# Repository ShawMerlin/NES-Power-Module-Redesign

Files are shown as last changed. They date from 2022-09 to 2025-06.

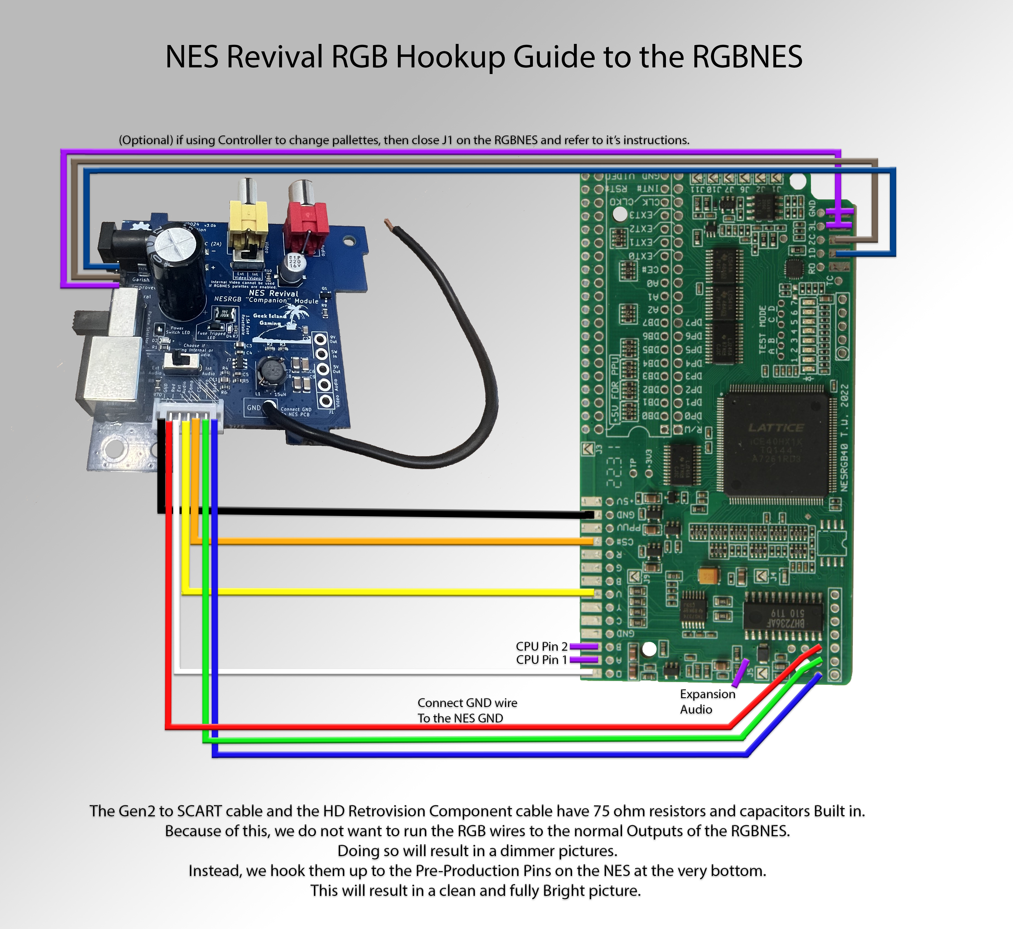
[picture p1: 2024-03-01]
RGB - Genesis 9 Pin Edition/NESRGB Hookup Instructions.jpg

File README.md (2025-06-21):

# NES Revival - Power-Module Redesign
Completely Redesigning the NES Power Module to Reduce Noise and EMI <br>
 <br>

6/21/2025
- I love this community, there has been a lot of folks reaching out.  I am doing well.  :)
- Zaxour, an amazing engineer and the person who helped me fix my design has his own version.
- I would highly recommend if you need a board to check his out.  - https://ko-fi.com/s/a42a9b282f
  
<br>
<br>
1/30/2025

I would like to thank the retro community for the love and support I have received over the years. <br>
At this time, I will no longer be offering these NES Boards on eBay or other channels. <br>
It's been a great couple of years but I must move on to other things in life. <br>
All of the Boards should have their Kicad files and Gerbers available on this Github. <br> <br>

It's not too bad ordering 5 of them pre-assembled from JLCPCB and then just sell the other 4 to get a free board.  :) <br>
I will not be able to provide support as well on these but I absolutely recommend the NES Help section on Dubesinhower Discord. <br>
https://x.com/dubesinhower?lang=en&mx=2 <br> <br>

There are a lot of amazing folks on that Discord Channel and in our community. <br>
Thank you for letting me be a part of it. <br>

-Merlin Shaw <br> <br> <br>

6/15/2024 <br>
Our first production run on NES Revival Classic RCA Editions have come in.  <br> <br>

6/4/2024 <br>
The NEW Revival RGBNES "Companion" Power Module production files have been released on this Github. <br> <br>

5/8/2024 <br>
I have my first RGB "Companion" 3.1c production boards run ready for eBay.  <br> <br>

4/5/2024 <br>
The RGBNES "Companion" Power Board v3.1b has passed it's prototype phase and I am ordering a production run. <br>
We are getting close to being able to release the gerber files for this design.  I just want to verify with the new order. <br> <br>

3/2/2024  <br>
GND Loop Issue Discovered on Older Boards and a Quick DIY Solution for it. <br>
https://github.com/ShawMerlin/NES-Power-Module-Redesign/blob/main/GND%20Loop%20Solution.md <br> <br>

2/13/2024 <br>
New Updates on the Rivial RGBNES 'Companion" Power Module <br>
https://github.com/ShawMerlin/NES-Power-Module-Redesign/blob/main/RGB%20-%20Genesis%209%20Pin%20Edition/readme.md <br> <br>

1/16/2024  <br>
I have a small sample of the new RGB "Companion" 3.0 Boards that are available  <br>
I will also update the classic design with the new features of the RGB Board and offer that one as well. <br>

https://github.com/ShawMerlin/NES-Power-Module-Redesign/tree/main/RGB%20-%20Genesis%209%20Pin%20Edition  <br>



<br> <br>

The original NES Power Module from the 80's is very noisy.  The Power Traces cross eachother and the ground home path is messy.
EMI was not a worry in 1985 but noise can impact picture and sound quality

Project is Open Sourced with a MIT License. It can be edited, changed and sold at your own discretion.  
Please link back here if this helps you with your own project.

=-=-=-Special Thanks to Project Guardian-=-=-=

# Goals with these new NES Power Modules
- Full Ground Plane that is uninterrupted and is free of traces and components.
- Power Traces that do not cross and have the GND plane below for a good return power signal.
- Have a specific NES Power Module for each use case (not try and pile everything into one board)

# NES Classic USB C Powered Module


# USB C Powered - NESRGB Companion Power Module with YPbPr "Component" Video


# NES Classic with Composite Out and Two Channel Mono Sound.


# NES RGB with Genesis 2 9 Pin Output


# Full uninterrupted ground plane on the back of the board.


# An easy to solder DIY Version of the Classic Composite RCA Edition.


# For the few that own the NES HDMI Board, this module will provide very easy solder points without the need of the LDO.


# Below is an example of the Orignal Power Module.  Notice how the power traces keep crossing eachother and other components. Folks really didn't consider EMI a lot back then and opted to just cover the entire board in a metal shroud.



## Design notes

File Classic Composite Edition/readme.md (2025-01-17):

**1/15/2025 - Version 3.1c** <br>
- Updated a mistake in the BOM for the Digikey Part number to be correct on the Q1 Transistor. <br>
-  https://www.digikey.com/en/products/detail/evvo/2SA1015/22482092 <br> <br>
- Updated C12 to be 560pF, 1nF will work fine but 560pF produces a slightly sharper picture. <br>
-  https://www.digikey.com/en/products/detail/kemet/C0805C561J5GACAUTO/10642381 <br> <br>
- Updated Switching Regulator from Digikey to the H Variant in the BOM - 1/17/2025 <br>
-  https://www.digikey.com/en/products/detail/texas-instruments/TPS54202HDDCR/6026259 <br> <br>

**6/15/2024 - Version 3.1c** <br>
- It's been a long time coming but I wanted to make sure the RGBNES Versions were perfect. <br>
- This uses the exact same voltage regulator as the RGBNES Compantion Board. <br>
- GND Loop issue has been resolved. <br>
- 2 Audio Ports to give Duo Mono Sound. <br>
- Gerbers will be released for this later next week. <br>



**2/06/2024 3.0 Update** <br>
- I am in the process of testing our new 3.0 design with lots of great feedback from our community. <br>
- At this time, I do not recommend having any of the 2.0 boards built. <br>
- If you have already invested time/money into the older boards, Please contact me so we can work something out. <br>
- I have an official Statement on these new boards within a few weeks. <br>  <br>

**4/01/2023 2.1 Update**
- Create a Full Bridge Rectifier out of SMC Diodes for better heat dissapation into the PCB Board.
- Changed the 6.8uH Inductor to a 10uH inductor per the datasheet in order to reduce noise.
- Added an Input Inductor on the voltage regulator to reduce ringing on the circuit.
- Added a 1.9A Fuse for safety and including a tripped fuse LED indicator.
- Added more filtering caps on the 5v Output (47uF, 22uF, .1uF, 50pF)



**2/14/2023 2.0 Update**
- Upgraded the Full Bridge Rectifier to one that can do 5 Amps. The old version was getting pretty warm.
- Beefier DC Input Jack that can handle 5 Amps (old one could only do 2.5 amps)
- This Board has been tested pulling 3 Amps max without issue.
- Ground stitching over audio traces to help prevent any static and noise that would be coming from the Buck Converter.
- The Power LED turns on now when the Solder Bridge has been made. Meaning it can be disabled by removing the bridge.
- Most all parts are SMD now and made easy for an Assembly House like JLCPCB to build the PCB and Assemble for you.
- BOM and POS files are included that Assembly Houses will need.

**9/19/2022 Update**
- Version 1.8 - Increased the Ground Stitching around the Video Trace and added Ground Stitching to the Audio Trace.

I have uploaded the Gerbers for this board and also a Bill of Materials and Position File.
You can use both these .CSV files to have JLCPCB provide and Assemble the SMD parts for you.

# Picture Showcase!!









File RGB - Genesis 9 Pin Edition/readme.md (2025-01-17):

# NES Revival RGBNES "Companion" Power Module.   <br>

1/15/2024 <br>
- over 100 of these 3.1c boards have been sent out on my eBay store.
- A few installation errors but we have not seen any buck converters giving up the smoke!
- Corrected a mistake in the Digikey part number of the Q1 Transistor, the JLCPCB number was correct.
- We are recommending a 560pF instead of the 1nF capacitor on C12, this provides a slightly crisper image.
- Added the H variant of the switching regulator to the Digikey BOM.

6/4/2024 <br>
- Production files have been released for version 3.1c <br> <br>

5/8/2024 - Version 3.1c is production ready, Gerbers will be released this week. <br>
I have a full analsyis with aid from Zaxour to show peformance levels for these boards. <br> <br>

<br> <br>
3/1/2024 - Testing of the new Design 3.0b is going well.  <br>
- We have moved to a 4 layer board to increase the coupling of the switching components to the inner GND layers. <br>
- The Switch input is only used now to power the enable pin on the Buck Converter.  The Input power comes directly from the board itself. <br>
- GND to NES Connector has been moved closer to the Voltage Regulator to reduce the GND Loop area. <br>
- Inductor has been moved further away from the interconnect pins and more bypass capacitors have been added to help reduce noise. <br>
- I plan on doing a more indepth analsys of this design vs the older design and releasing the results. <br>
- All Kicad files and Gerber files will be released once testing is completed. <br>



 <br>  <br>
2/13/2024 - Production Boards have been ordered. <br>
- Testing has been going great!!  I have now ordered my first production run. <br>
- With some help from this great community, I have made improvments to the design. <br>
- I plan on releasing a full breakdown of these new boards and some words on older designs. <br>
- Open Source Files will be released once the Production Boards are verified <br> <br>

1/16/2024 - Features of the 3.0 Boards  <br>
- Stable and clean 5.06 volts at a 1.5A load.  (7.5 watts) <br>
- Tested for 48 hours at a 1.8A load (9 watts) <br>
- Peaks of 2A are fine, but it's pushing the components pretty hard. <br>
- 1.5A Resettable Fuse on 9V input for board protection. (13.5 watts) <br>
- The LCSC Chinese Voltage Regulator has been replaced with a TE Connectivity IC. (TPS54202) <br>
- The Full Bridge Rectifier is a Diode Incorporate part. (MSB30M) <br>
- All Parts can be obtained from Digi-Key/Mouser. <br>
- Gerbers and Kicad files will be released once testing burn-in is complete. <br>
- I also plan on offering these again on my eBay account once i'm done with testing. <br>



<br> <br>
4/30/2023 - <br> <br>
When connecting the RGBNES to this PWR Module, do not use the main RGB Headers on the RGBNES. <br>
- The Gen2 Cables have circuits in them to treat the RGB Signal.  The main RGB Headers on the RGBNES are also treating the RGB Signal. <br>
- If these header points are used, the picture will be a lot darker as a result. <br>
- There are other points on the RGBNES that can be used that have the RAW RGB Data before all the processing. <br>
- Use of the RAW RGB points will allow the picture's brightness to be accurate and good. <br>
- Reference these pins [HERE](https://github.com/ShawMerlin/NES-Power-Module-Redesign/blob/main/RGB%20-%20Genesis%209%20Pin%20Edition/Features%20and%20Components.md) <br>

   <br>

4/03/2023 - Newer features of the 2.1 Boards <br>
- Using JST 2.0 PH Connectors now so the wires are not so microscopic. <br>
- Updated the Audio Selection Switch to also control Audio Output on the Gen2 Port. <br>
- Added the Internal Componsite Circuit so now this board can be fully used without a RGBNES Installed. <br>
- Video Selection switch will now control whether Int or Ext Video is outputted on the RCA Jack. <br>
- If Dual Mono Audio is desired, a simple RCA Y Splitter cable can be used on the Red RCA Jack. <br>

3/13/2023 <br>
Gerbers, BOM and POS (JLCPCB Assembly) have been released and are on this github page. <br>

Key Features on this board.
- Switching Voltage Regulator.  This outputs a lot less heat and a stable 5V Supply.
- Seperate Ground Plane from the 5V Regulator and the RGB Traces.  2 Grounding points on the Board. 
- Physical cut outs in the PCB board to help shield against any EMI from the regulator.
- Switch for selection of Internal Audio or External Audio (if you have your own Audio Circuit)
- Switch for Selection of the Multi-Function RCA Jack to be Left (mono Audio) or Composite from the RGB Board.
- 3 Way Side Switch that can be wired into the Palette Selection on the RGB Board - 
- Gen2 Output is compatible with the Scart Adapters, HDRetrovision Cable, OSSC and the Retrotink.  
- The RGBNES offers Raw RGB Output pads as the Gen2 Cables will add 75 ohm resistors. Check instructions for more details.

Click here for a list of the features this board offers - [Link](https://github.com/ShawMerlin/NES-Power-Module-Redesign/blob/main/RGB%20-%20Genesis%209%20Pin%20Edition/Features%20and%20Components.md)

Click here for Instructions on how to install this Power Module - [Link](https://github.com/ShawMerlin/NES-Power-Module-Redesign/blob/main/Install_Instructions.md)

(RGBNES Required for the Gen2 Port on this No Cut Mod Board, Normal Componsite and Audio will still work without it.) <br>

Shoutout to Long Island Retro Gaming for the screenshot!! - https://www.youtube.com/@LIRetroGaming






<br> <br>
Update History <br>

3/20/2023 - Feedback from testers has been excellent.  I have received great feedback which is being done in the next revision.  <br>  <br>
Revisions for V2.1
- Removed the ability to use the multifuction port as an Audio Port.  It is now Video Componsite Only.  <br>
- Added the internal Composite circuitry back to the Power Board and made the seldctor switch, Int Video and Ext Video.  <br>

3/2/2023 - Testing is going good.  I am sending engineering samples to various testers in order to get feedback. <br>

Final Revision for V2.0 that brings some quality of life updates. <br>
- Moved the Optional Power LED to a more central location.  <br>
- Changed the Pitch from JST XH 1.5mm to JST PH 2.0mm to make it a lot easier to solder without bridges.  <br>
- Rotated JST Connector so now a right angle one can be used.  <br>
- Gen2 Audio Output now is controlled by the Ext/Int Audio Switch. <br>
- Rotated the Palette Switch outputs for easier access. <br> <br>

2/28/2023 - Boards have arrived and are assembled.  I couldn't find my Gen2 9 Pin to SCART cable so I had to order a new one.  <br>
It sohuld arrive today and after testing is complete.  All files will be released on this github. <br>

2/1/2023 - Getting back on the horse!!  I have Version 1.9 completed and ordered. I should be able to test within a couple of weeks.
This new version has slide switches instead of header jumpers and I have also changed the pinout on the 7 pin connector to match the color of wires.

9/12/2022 - I have made a couple of changes to the RGB Board, I have moved the 9 pin Genesis Connector closer and fixed part of the audio circuit.
The Gerber files have been taken down until we get this new one tested.

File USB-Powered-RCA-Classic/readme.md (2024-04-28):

4/27/2024 - The Prototype of the USB C PD Power Board has been ordered and we should be testing it at the end of next week. <BR>
I do plan on offering these for sell when they have completed testing. <BR> <BR>

4/5/2024 - I added information to the older USB C Design.  I still do not recommend using this design. <BR>
I am close to ordering my first prototype for the USB C PD Board.  The Evaluation board I got to test this has worked great. <BR>
I hope to order within a few weeks, i'm just trying to save up for the order.  <BR> <BR>
Here is a sneak peak  ;)   <BR>



<BR>
<BR>
3/31/2024 - Please note that I am currently working on a USB C PD version that will be a lot more stable. <BR>
The USB C Standard allows for voltages between 4.75 and 5.75 volts.  The NES does not like voltages under or above 5.0-5.1 volts. <BR>
So it was kit or miss when it came to what USB C Brick was used. <BR> <BR>

With USB C PD, we will output a stable 9 - 12 volts and then use a voltage regulator to output a stable 5.07 volts. <BR>
This regulator has been tested and found to only have a 23mV peak to peak. <BR>
I plan to have this design ready for release in about 4 weeks. <BR> <BR>

<BR> <BR>




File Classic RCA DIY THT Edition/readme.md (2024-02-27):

# NES Revival PWR Board DIY Edition

A DIY NES Power Module for at home assembly that uses a LDO instead of a buck converter to get the voltage to 5V <br>
To View the Virtual BOM without downloading, click here - <a href="https://htmlpreview.github.io/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">Virtual BOM</a>

2/26/2024 - An issue was discovered with the pinout on the Q1 Transistor.  Version 3.1C was created to fix this pinout issue.  If Version 3.1b  <br>
has already been ordered, you can still use it but you have to rotate the transistor 90 degrees to put the legs in the right holes.  <br> 
Please reach out to me through email if you need help with this.  <br> <br>

2/18/2024 - Changed to a 4 layer PCB Board to help with coupling the front and back layer to the inner gnd layers.  This is only a few more
dollars for the PCB but is well worth it for noise reduction. <br> <br>

1/28/2024 - Moved the NES GND Connection pad closer to the 7805 <br> <br>  

1/20/2024 - Complete Redesign on Version 3.0 to get the 7805 back to where it is on the original Power Module. <br>
This will allow for the orignal Heatsink to be used or Regulator TSR2-2450 if no Heatsink is wanted. <br>
Extra Modifications for a Common Mode Choke and Bypass Capacitors on 5V Out to help reduce all Noise. <br>

 <br>
 I added a Low Cost tab in the BOM if noise is not as big of a concern.  Savings is about $5 from selecting these parts.  <br>

2/14/2023 - Minor changes to V1.3 including a correction in one of the capacitor values on the silkscreen and putting hot indicators <br>
          - Gerbers are now available that can be used at your favorite PCB Fab House. <br> <br>





 <br> <br>

Key Features on this board. <br>
- No SMD Parts, All THT and easy to solder. <br>
- L78S05CV for 2 Amps of Power <br>
- Power Indicator LED is optional with a Solder Jumper to enable. <br> <br>

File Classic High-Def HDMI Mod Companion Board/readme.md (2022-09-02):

For the lucky few that got the NES HDMI Board while it was available, there is an option for it with our boards.
The NES HDMI Board uses the 9v input instead of the 5v regulated so there is no voltage regulator on this board.

Large Postive and Negative pads to make it easy to connect wires directly to the HDMI Board.



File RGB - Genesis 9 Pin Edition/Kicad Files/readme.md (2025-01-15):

*** 1/15/2025 ***
- KiCad PCB Designed files released for 3.1c
- I will work on getting clean schematics to release.

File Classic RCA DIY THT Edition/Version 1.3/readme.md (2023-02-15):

# NES Revival PWR Board DIY Edition

A DIY NES Power Module for at home assembly that uses a LDO instead of a buck converter to get the voltage to 5V <br>
Check out the Virtual BOM and Placement of these components on this Board.
[Link](https://htmlpreview.github.io/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)

2/14/2023 - Minor changes to V1.3 including a correction in one of the capacitor values on the silkscreen and putting hot indicators <br>
          - Gerbers are now available that can be used at your favorite PCB Fab House. <br> <br>

2/01/2022 - Version 1.2 ordered today.  Will test when they come in and then release Gerbers.
          - BOM is Available now, Gerbers will be available after testing.

Key Features on this board. <br>
- No SMD Parts, All THT and easy to solder. <br>
- L78S05CV for 2 Amps of Power <br>
- Heatsink with full ground plane on both layers underneath the Heatsink. <br>
- Should be printed with 2oz copper to help dissipate the heat. <br>
- Power Indicator LED is optional with a Solder Jumper to enable. <br> <br>















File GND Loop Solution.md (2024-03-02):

## A GND Loop discovery from the older NES Revival Power Modules.  <br>

I first must express my appreciation for the Retro Community.  Instead of tearing others down, they work to build and improve.  <br>
My mindset has always been that every design can be improved and I will always welcome any and all feedback.  <br>

A design flaw oversight was discovered from our power boards and community members brought this to my attention. <br>
The original GND to NES location was placed near the Full Bridge Rectifier with the thought of having a short retun path. <br>
My oversight was that the return path had to go all the way back to the Switching Regulator and then heads back to the rectifier.  <br>
This large GND Loop results in ringing and other undesirable impacts to the overall circuit. <br> 

While I do not believe that these power boards in the wild pose a danger to the NES, they will have a reduced life as a result.  <br>
Currently, I have only seen about a 4% failure rate on people reporting back to me. (Which I feel is still too high).   <br>
The whole idea behind this redesign from the beginning was to have a product that would last for years to come.  <br>

This GND Loop only impacts the Power Boards with Switching Regulators.  It does not exist on the 7805 designs. <br>
The suggestion for 2oz copper on the 7805 designs was to provide more copper for heat dissipation and not to couple noise frequencies. <br>
I would like the express my thanks to the Dubesinhower Discord Group for bringing this to my attention. <br>
I would also like to personally thank Zaxour for assisting with the new design layout. - https://twitter.com/zaxour  <br>

If you have one of these boards that has failed and have not yet contacted me.  Please reach out so I can provide a full replacement at no cost. <br>
To make right to the community that I love,  I have 2 options for those that have a NES Revival Power Board and would like this fixed.  <br>  <br>

## Option #1 - A quick DIY Fix to shorten the GND Loop on the Power Board itself  <br>

- Step 1 Just right of the bottom interconnect pin, scrap back the soldermask  <br>
309180911-02046060-b7c6-4868-9515-8014584bc00d

- Step 2 Place a ball of solder on this exposed GND section.  <br>


- Step 3 Connect a GND Wire to that newly created pad and connect it to a nearby GND point on the NES Main Board <br>


- Step 4 Disconnect the original GNDing wire so that it's no longer on either the power module or the NES Main Board.<br>

## Option #2 - A replacement Power Module will be offered at a heavily discounted rate.  <br>
- If you have spent money/resources in any of these designs and would like a full replacement.  Please reach out to me. <br>
- My email is Merlin(dot)Shaw@gmail(dot)com.  Let me know how many replacements you need to cover the boards you have made/purchased. <br>
- I will add your name to a list for replacements and will work to get through the list in a timely but realistic fashion. <br>
- The discount on the board will cover my costs and shipping. <br>

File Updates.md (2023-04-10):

# Updates
- 4/10/2023 - New RGBNES Companion PWR Boards Version 2.1 are completed and fully tested.(I will upload design files shortly) <br>
            - Still working on the 5.2V Clamp on the USB Boards to send all voltages above 5.2V to GND and trip a resettable fuse. <br>

- 3/31/2023 - New RCA Classic Modules v2.1 have been tested and are working great. <br>
Features a 1.9A fuse to help protect the circuit and main NES Board, input inductor, Diode Rectifier and more filtering capacitors <br>
- 3/13/2023 - The NES NESRGB "Companion" Power Module is completed and tested.  Files released under this github. <br>
- 2/14/2023 - DIY Boards have tested good with a 2 amp load for 24 hours.  I updated a footprint and added some warning graphics to the board.  Gerbers files have been released. <br>
- 2/12/2023 - The DIY Board has arrived and it has been assembled. Testing will finish up tonight and I will release the Kicad/Gerber files once testing is done. <br>
- 2/12/2023 - The Vertical USB C proved to not be the most solid or stable when I was stress testing it with twisting and plugging in the cable. This has been replaced. <br>
- 2/12/2023 - The 'Y'Pb'Pr Component output board is working but is oversaturated on the blue channel.  More research is being done. <br>
- 2/12/2023 - NES RGB Gen2 Power Module is currently in-transit. I will be testing this as soon as it arrives.

- 2/1/2023 - Getting back on the horse!! I have NES RGB Gen2 Power Module Version 1.9 completed and ordered. I should be able to test within a couple of weeks. 
  This new version has slide    switches instead of header jumpers and I have also changed the pinout on the 7 pin connector to match the color of wires.

- 2/1/2023 - Redesigned the THT DIY Board so that it uses a LDO once again and uploaded the BOM files.  Testing the PCB is our next step.

- 1/8/2022 I have added to my designs a USB C Powered Module (This was long overdue).
  This module uses Power Delivery to get up to 3 amps of 5V Power from a USB Power Brick.
  It does not need to coverted down to 5V so no buck converters or LDO's needed!!
  
- 10/18/2022 - The YPbPr Component board has to have the 3.5mm jack changed positions.  The case doesn't quite have a low enough lip to
 support it and I want to keept his a No-Cut Mod.  I plan on putting it up where the old Video Out use to be and will upload photo's when I have this completed.

- 9/22/2022 - Working on a Classic and 'Y'Pb'Pr "Component" Version that uses the LDO instead of the Switching Voltage Regulator.  

  Lots of heat but I have some ideas on how to handle it.

- 9/17/2022 - I tested the Component (Y/pB/pR) circuit with the NESRGB Board and it looked great!!  I have these new PCBs on order

- 9/12/2022 - I found a couple of issues on the Sound and RGB Board which are being fixed.  The Classic and THT Versions are still good.
 Added new concept of a Component Output board and created a folder for it with Pictures.

- 9/10/2022 - Sound Mix board needed a couple of small changes but the RGB, DIY THT, and new HDMI Companion board are working great!!
 I will be updating the folders on this github with those gerber files too.

- 8/24/2022 - Uploaded BOM, Gerber and Kicad Files for the DIY THT Classic RCA Power Module. 
- 8/22/2022 - Starting tests on the Sound Mix and RGB Edition.
  
  I have also added a new version below for the HDMI Hi-Def Mod.
- 7/13/2022 - First Production batch of Classic Power Module arrived.  Kicad files available and uploaded!

  I have also ordered the Soundmix and RGB Boards.
- 7/02/2022 - Prototypes for the Classic Power Module with Composite Video were successful!! 
  
  Gerbers, Bill of Materials and Assemly Position files have been uploaded above.
- 6/19/2022 - Replaced the LDO with a Switching Voltage Regulator for a low heat alternative.  New boards ordered. Expected by 6/27.
- 5/30/2022 - BOM created for Classic RCA Power Board and Uploaded, boards expected by 6/3.
- 5/17/2022 - Both Classic and Classic with Sound AMP PCBs have been ordered for testing.  
- Once verified, the open source files will be released.

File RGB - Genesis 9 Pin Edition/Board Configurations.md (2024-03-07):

The next rendition of the RGB Board will have the selector switches removed in favor of Solder Jumpers. <br>

# Solder Jumper Configurations <br>

The Boards will come pre-configured for both External Video and Audio (S1 & S3) <br>
If Internal Video or Audio is desired, then the above solder jumpers will have to be desoldered. <br>

## Audio Selection *(Select either S1 or S2 but not both)* <br>
- S1 - External Audio <br>
- S2 - Internal Audio <br>
## Video Selection  *(Select either S3 or S4 but not both)* <br>
- S3 - External Video <br>
- S4 - Internal Video <br>
- S5 - Int Video Enable (Must be enabled if using S4) <br>
## Power LED
- S6 - Power LED Enable <br>

The board's internal audio circuit will not work if the RGBNES Pallettes are used. <br>
Bascially if using the RGBNES, External Video will be the only option that can be used. <br>
Desolder S4 & S5 if using the RGBNES and solder S3. <br> <br>

S1 & S3 are both external inputs, these come directly from the J8 JST Cable. <br>
These must be hooked up to the RGBNES's outputs in order for them to work correctly. <br>



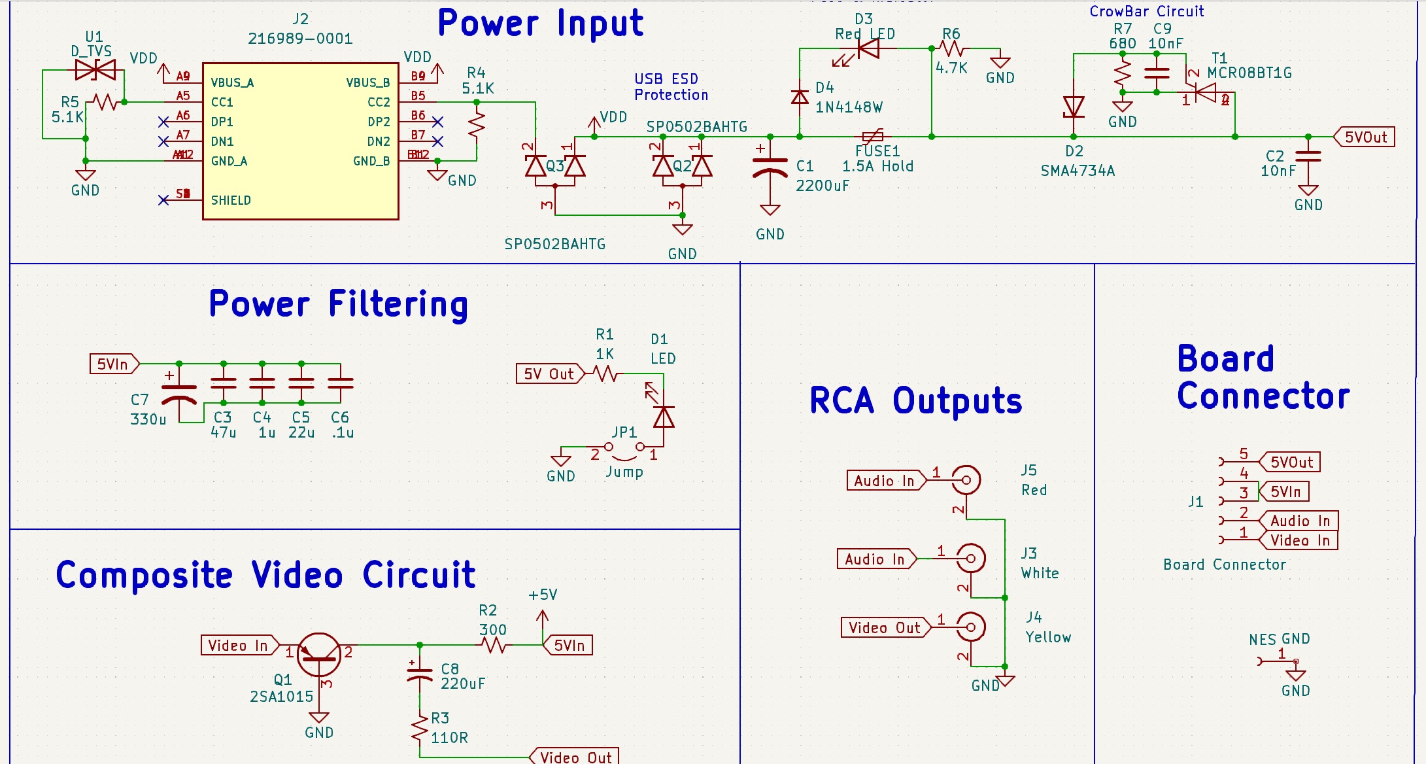
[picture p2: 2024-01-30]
USB-Powered-RCA-Classic/Schematic-NES_PowerBoard_USB C_RCA_V1.5.jpg

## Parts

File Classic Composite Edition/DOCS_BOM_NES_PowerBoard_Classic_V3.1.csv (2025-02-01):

Comment | Designator | SMD Footprints | LCSC | Mouser
2200uF | C1 | Capacitor_THT:CP_Radial_D12.5mm_P5.00mm | C445125 | https://www.digikey.com/en/products/detail/nichicon/UVZ1E222MHD/589047
10nF | C2 | C_0805_2012Metric | C1710 | https://www.digikey.com/en/products/detail/samsung-electro-mechanics/CL21B103KBANNNC/3886673
10uF | C3 | C_0805_2012Metric | C15850 | https://www.digikey.com/en/products/detail/samsung-electro-mechanics/CL21A106KAYNNNE/3888549
.1uF | C4,C5 | C_0603_1608Metric | C14663 | https://www.digikey.com/en/products/detail/yageo/CC0603KRX7R9BB104/2103082
10nF | C6 | C_1206_3216Metric | C1846 | https://www.digikey.com/en/products/detail/murata-electronics/GRM3195C1H103JA01D/586883
22uF | C7,C8 | C_1206_3216Metric | C12891 | https://www.digikey.com/en/products/detail/murata-electronics/GRM31CR71A226KE15L/2039036
.1uF | C9 | C_1206_3216Metric | C24497 | https://www.digikey.com/en/products/detail/murata-electronics/GRM31C5C1H104JA01K/2548138
220uF | C10 | CAP-SMD_BD6.3-L6.5-W6.5-LS7.0-FD | C125979 | https://www.digikey.com/en/products/detail/nichicon/PCJ0J221MCL1GS/1662427
75pF | C11 | C_0805_2012Metric | C5375865 | https://www.digikey.com/en/products/detail/yageo/CC0805JRNPO9BN750/5884054
560pF | C12 | C_0805_2012Metric | C520091 | https://www.digikey.com/en/products/detail/kemet/C0805C561J5GACAUTO/10642381
MSB30M | D1 | MSBL | C460923 | https://www.digikey.com/en/products/detail/diodes-incorporated/MSB30M-13/7353064
Green_LED | D2 | LED_SMD:LED_0805_2012Metric | C2297 | https://www.digikey.com/en/products/detail/liteon/LTST-C171GKT/386793
1N4148W | D3 | D_SOD-123 | C7420318 | https://www.digikey.com/en/products/detail/smc-diode-solutions/1N4148W/6022450
Red LED | D4 | LED_0603_1608Metric | C2286 | https://www.digikey.com/en/products/detail/liteon/LTST-C191KRKT/386837
MINISMDC150F/16-2 | FUSE1 | F1812 | C2649921 | https://www.digikey.com/en/products/detail/littelfuse-inc/MINISMDC150F-16-2/2319761
EJ503A | J2 | THT | C3095117 | https://www.digikey.com/en/products/detail/mpd-memory-protection-devices/EJ503A/5431753
TPS54202HDDCT | J7 | SOT-23-6 | C134129 | https://www.digikey.com/en/products/detail/texas-instruments/TPS54202HDDCR/6026259
15uH | L1 | 7.2x6.9x4.5mm Copy | C2836220 | https://www.digikey.com/en/products/detail/tdk-corporation/CLF7045NIT-150M-D/5812243
2SA1015 | Q1 | SOT-23 | C181170 | https://www.digikey.com/en/products/detail/evvo/2SA1015/22482092
4.7K | R1 | R_0805_2012Metric | C17673
120K | R2 | R_0603_1608Metric | C25808 | https://www.digikey.com/en/products/detail/yageo/AC0603FR-07105KL/5895738
511K | R3 | R_0603_1608Metric | C2684557 | https://www.digikey.com/en/products/detail/yageo/RC0603FR-07511KL/727288
100K | R4 | R_0603_1608Metric | C25803 | https://www.digikey.com/en/products/detail/yageo/RC0603FR-07100KL/726889
13.3K | R5 | R_0603_1608Metric | C321713 | https://www.digikey.com/en/products/detail/yageo/RT0603BRD0713K3L/1072240
49.9R | R6 | R_0603_1608Metric | C23185 | https://www.digikey.com/en/products/detail/yageo/RC0603FR-0749R9L/727264
4.7K | R7 | R_0603_1608Metric | C23162 | https://www.digikey.com/en/products/detail/yageo/RC0603FR-074K7L/727212
300R | R8 | R_0805_2012Metric | C17617 | https://www.digikey.com/en/products/detail/yageo/RC0805FR-07300RL/727848
110R | R9 | R_0805_2012Metric | C246031 | https://www.digikey.com/en/products/detail/yageo/RC0805FR-07110RL/727559
Comment | Designator | Through Hole FootPrints | LCSC
Palette Switch | SW1 | THT |  | EG2215 *JLCPCB has a global source for this
Yellow RCA (If using Componsite) | J3 | Yellow RCA Jack for Video |  | RCJ-044
Red RCA | J5 | Red RCA Jack for Audio |  | RCJ-042
9 Pin Gen2 Connector | J9 | 9 Pin Gen2 Connector |  | MD-90SM
3 Pin JST with cable for connecting to Palette | J12is |  |  | https://www.amazon.com/2-54MM-Female-Single-Connector-300mm/dp/B01IZAING4

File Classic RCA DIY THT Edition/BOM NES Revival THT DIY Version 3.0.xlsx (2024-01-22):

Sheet: Low Noise
Designator | Type | Rating | Other | Brand | Model | Optional | QTY | Price | Total
C1 | Capacitor | 2000uF |  | TDK | B41821F5228M000 |  | 1 | $1.00 | $1.00 | https://www.digikey.com/en/products/detail/epcos-tdk-electronics/B41821F5228M000/3544323
C2,C10 | Capacitor | 10nF | C0G, NP0 | TDK | FG26C0G2J103JNT06 |  | 2 | $0.77 | $1.54 | https://www.digikey.com/en/products/detail/tdk-corporation/FG26C0G2J103JNT06/5803020
C3 | Capacitor | 47uF | X5R | TDK | FG22X5R1A476MNT06 |  | 1 | $1.36 | $1.36 | https://www.digikey.com/en/products/detail/tdk-corporation/FG22X5R1A476MNT06/5802928
C4 | Capacitor | 1uF | X7R | TDK | FG26X7R1E105KNT06 |  | 1 | $0.36 | $0.36 | https://www.digikey.com/en/products/detail/tdk-corporation/FG26X7R1E105KNT06/5803050
C5 | Capacitor | 22uF | X7R | TDK | FG20X7R1C226MRT06 |  | 1 | $0.85 | $0.85 | https://www.digikey.com/en/products/detail/tdk-corporation/FG20X7R1C226MRT06/5802908
C6,C11 | Capacitor | .1uF | C0G, NP0 | TDK | FG16C0G1H104JNT06 |  | 2 | $0.77 | $1.54 | https://www.digikey.com/en/products/detail/tdk-corporation/FG16C0G1H104JNT06/5802759
C7 | Capacitor | 330nF |  | Kemet | A750BG337M0JAAE020 |  | 1 | $0.50 | $0.50 | https://www.digikey.com/en/products/detail/kemet/A750BG337M0JAAE020/6196434
C8 | Capacitor | 220uF |  | Kemet | A750EK227M1CAAE016 |  | 1 | $0.50 | $0.50 | https://www.digikey.com/en/products/detail/kemet/A750EK227M1CAAE016/6196322
C9 | Capacitor | 560pF | C0G, NP0 | TDK | FG28C0G1H561JNT06 |  | 1 | $0.25 | $0.25 | https://www.digikey.com/en/products/detail/tdk-corporation/FG28C0G1H561JNT06/5803118
C12 | Capacitor | .33uF | X7R | TDK | FG14X7R1H334KNT06 |  | 1 | $0.35 | $0.35 | https://www.digikey.com/en/products/detail/tdk-corporation/FG14X7R1H334KNT06/5802753
DB1 | Bridge Rectifier | 2A |  | Retcon | RC204 |  | 1 | $0.64 | $0.64 | https://www.mouser.com/ProductDetail/583-RC203
J2 | Barrel Jack | 5.5 x 2.1mm |  | MPD | EJ503A |  | 1 | $1.38 | $1.38 | https://www.digikey.com/en/products/detail/mpd-memory-protection-devices/EJ503A/5431753
J3 | RCA Jack | White |  | CUI Devices | RCJ-043 |  | 1 | $1.66 | $1.66 | https://www.digikey.com/en/products/detail/cui-devices/RCJ-043/408507
J4 | RCA Jack | Yellow |  | CUI Devices | RCJ-044 |  | 1 | $1.66 | $1.66 | https://www.digikey.com/en/products/detail/cui-devices/RCJ-044/408508
J5 | RCA Jack | Red |  | CUI Devices | RCJ-042 |  | 1 | $1.66 | $1.66 | https://www.digikey.com/en/products/detail/cui-devices/RCJ-042/408506
Q1 | Transistor | PNP |  | Onsemi | KSA1015YTA |  | 1 | $0.39 | $0.39 | https://www.digikey.com/en/products/detail/onsemi/KSA1015YTA/1051646
R2 | Resistor | 300R |  | TE Connectivity | ROX05SJ300R |  | 1 | $0.24 | $0.24 | https://www.digikey.com/en/products/detail/te-connectivity-passive-product/ROX05SJ300R/9926117
R3 | Resistor | 110R |  | TE Connectivity | ROX05SJ110R |  | 1 | $0.18 | $0.18 | https://www.digikey.com/en/products/detail/te-connectivity-passive-product/ROX05SJ110R/9926107
U1 | Voltage Regulator | 2A |  | STMicro | L78S05CV | TSR2-2450 | 1 | $1.07 | $1.07 | https://www.digikey.com/en/products/detail/stmicroelectronics/L78S05CV/585989
D1 | LED | 3mm |  | KingBright | WP424GDT | Optional | 1 | $0.41 |  | If you want a power on LED Indicator.
R1 | Resistor | 680R |  | TE Connectivity | ROX05SJ680R | Optional | 1 | $0.24 |  | If you want a power on LED Indicator.
SW1 | Switch | E-Switch |  | DPDT | EG2215 | Optional | 1 | $0.94 |  | Only if you have a mod that requires a switch.
T1 | Choke | 47 µH @ 10 kHz |  | Würth Elektronik | 744841247 | Optional | 1 | $3.51 |  | Reduces Common Mode Noise. The NES Top Loader uses this.
 |  |  |  |  |  |  |  |  | $17.13

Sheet: Cost Effective
Designator | Type | Rating | Other | Brand | Model | Optional | QTY | Price | Total
C1 | Capacitor | 2000uF |  | RubyCon | 16PK2200MEFC10X20 |  | 1 | $0.63 | $0.63 | https://www.digikey.com/en/products/detail/rubycon/16PK2200MEFC10X20/3134077
C2,C10 | Capacitor | 10nF | X7R | Vishay | K103K10X7RF53L2 |  | 2 | $0.23 | $0.46 | https://www.digikey.com/en/products/detail/vishay-beyschlag-draloric-bc-components/K103K10X7RF53L2/2820426
C4 | Capacitor | 1uF | X7R | TDK | FG26X7R1E105KNT06 |  | 1 | $0.36 | $0.36 | https://www.digikey.com/en/products/detail/tdk-corporation/FG26X7R1E105KNT06/5803050
C5 | Capacitor | 22uF | X5R | TDK | FK24X5R0J226MR000 |  | 1 | $0.46 | $0.46 | https://www.digikey.com/en/products/detail/tdk-corporation/FK24X5R0J226MR000/2815422
C6,C11 | Capacitor | .1uF | X7R | TDK | FG18X7R1H104KNT06 |  | 2 | $0.24 | $0.48 | https://www.digikey.com/en/products/detail/tdk-corporation/FG18X7R1H104KNT06/5802879
C7 | Capacitor | 330nF |  | Kemet | A750BG337M0JAAE020 |  | 1 | $0.50 | $0.50 | https://www.digikey.com/en/products/detail/kemet/A750BG337M0JAAE020/6196434
C8 | Capacitor | 220uF |  | Kemet | A750EK227M1CAAE016 |  | 1 | $0.50 | $0.50 | https://www.digikey.com/en/products/detail/kemet/A750EK227M1CAAE016/6196322
C9 | Capacitor | 560pF | C0G, NP0 | TDK | FG28C0G1H561JNT06 |  | 1 | $0.25 | $0.25 | https://www.digikey.com/en/products/detail/tdk-corporation/FG28C0G1H561JNT06/5803118
C12 | Capacitor | .33uF | X7R | TDK | FK14X7R1H334K |  | 1 | $0.33 | $0.33 | https://www.digikey.com/en/products/detail/tdk-corporation/FK14X7R1H334KN020/2256792
DB1 | Bridge Rectifier | 2A |  | Retcon | RC204 |  | 1 | $0.64 | $0.64 | https://www.mouser.com/ProductDetail/583-RC203
J2 | Barrel Jack | 5.5 x 2.1mm |  | CUI Devices | PJ-037AH |  | 1 | $0.63 | $0.63 | https://www.digikey.com/en/products/detail/cui-devices/PJ-037AH/1644547
J3 | RCA Jack | White |  | CUI Devices | RCJ-043 |  | 1 | $1.66 | $1.66 | https://www.digikey.com/en/products/detail/cui-devices/RCJ-043/408507
J4 | RCA Jack | Yellow |  | CUI Devices | RCJ-044 |  | 1 | $1.66 | $1.66 | https://www.digikey.com/en/products/detail/cui-devices/RCJ-044/408508
J5 | RCA Jack | Red |  | CUI Devices | RCJ-042 |  | 1 | $1.66 | $1.66 | https://www.digikey.com/en/products/detail/cui-devices/RCJ-042/408506
Q1 | Transistor | PNP |  | Onsemi | KSA1015YTA |  | 1 | $0.39 | $0.39 | https://www.digikey.com/en/products/detail/onsemi/KSA1015YTA/1051646
R2 | Resistor | 300R |  | TE Connectivity | ROX05SJ300R |  | 1 | $0.24 | $0.24 | https://www.digikey.com/en/products/detail/te-connectivity-passive-product/ROX05SJ300R/9926117
R3 | Resistor | 110R |  | TE Connectivity | ROX05SJ110R |  | 1 | $0.18 | $0.18 | https://www.digikey.com/en/products/detail/te-connectivity-passive-product/ROX05SJ110R/9926107
U1 | Voltage Regulator | 2A |  | STMicro | L78S05CV | TSR2-2450 | 1 | $1.07 | $1.07 | https://www.digikey.com/en/products/detail/stmicroelectronics/L78S05CV/585989
C3 | Capacitor | 47uF | X5R | TDK | FG22X5R1A476MNT06 | Optional | 1 | $1.36 |  | Helps with Noise but if looking to cut costs, it's optional.
D1 | LED | 3mm |  | KingBright | WP424GDT | Optional | 1 | $0.41 |  | If you want a power on LED Indicator.
R1 | Resistor | 680R |  | TE Connectivity | ROX05SJ680R | Optional | 1 | $0.24 |  | If you want a power on LED Indicator.
SW1 | Switch | E-Switch |  | DPDT | EG2215 | Optional | 1 | $0.94 |  | Only if you have a mod that requires a switch.
T1 | Choke | 47 µH @ 10 kHz |  | Würth Elektronik | 744841247 | Optional | 1 | $3.51 |  | Reduces Common Mode Noise. The NES Top Loader uses this.
 |  |  |  |  |  |  |  |  | $12.10

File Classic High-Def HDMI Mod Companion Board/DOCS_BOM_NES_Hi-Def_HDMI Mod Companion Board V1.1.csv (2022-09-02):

Comment | Designator | SMD Footprints | LCSC | Mouser
10nF | C2 | Capacitor_SMD:C_0805_2012Metric | C1710
Green_LED | D2 | LED_SMD:LED_0805_2012Metric | C2297
2K | R1 | Resistor_SMD:R_0805_2012Metric | C17798
300R | R2 | Resistor_SMD:R_0805_2012Metric | C17617
110R | R3 | Resistor_SMD:R_0805_2012Metric | C17423
2SA1015 | Q1 | Package_TO_SOT_SMD:SOT-23 | C545569
Comment | Designator | Through Hole FootPrints | LCSC | Mouser
2200uF | C1 | Capacitor_THT:CP_Radial_D12.5mm_P5.00mm | C225868 | UVZ1E222MHD
100uF | C5 | Capacitor_THT:CP_Radial_D6.3mm_P2.50mm |  | 50ML1MEFC4X5
220uF | C8 | Capacitor_THT:CP_Radial_D6.3mm_P2.50mm | C2897445 | 6SEPC220M+TSS
Power Jack | J1 | 2.1mm ID, DC Power Supply Connector, 2 Pin |  | PJ-037A
Red RCA |  | Right Audio - Red RCA Jack |  | RCJ-042
White RCA |  | Left Audio - White RCA Jack |  | RCJ-043
Yellow RCA |  | Video Out Yellow RCA Jack |  | RCJ-044
AC->DC |  | Bridge Rectifiers VR=600V IAV=2.0A |  | DF206ST-G

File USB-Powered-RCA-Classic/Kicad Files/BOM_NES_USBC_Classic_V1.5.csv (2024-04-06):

Comment | Designator | SMD Footprints | LCSC | Website
2200uF | C1 | SMD,D12.5xL13.5mm | C99834 | https://www.lcsc.com/product-detail/Aluminum-Electrolytic-Capacitors-SMD_ROQANG-RVT1A222M1213_C99834.html
10nF | C2,C9 | C_0805_2012Metric | C1710 | https://www.lcsc.com/product-detail/Multilayer-Ceramic-Capacitors-MLCC-SMD-SMT_Samsung-Electro-Mechanics-CL21B103KBANNNC_C1710.html
47uF | C3 | C_0805_2012Metric | C76636 | https://www.lcsc.com/product-detail/Multilayer-Ceramic-Capacitors-MLCC-SMD-SMT_TDK-C2012X5R1A476MTJ00E_C76636.html
1uF | C4 | C_0805_2012Metric | C28323 | https://www.lcsc.com/product-detail/Multilayer-Ceramic-Capacitors-MLCC-SMD-SMT_Samsung-Electro-Mechanics-CL21B105KBFNNNE_C28323.html
22uF | C5 | C_0805_2012Metric | C45783 | https://www.lcsc.com/product-detail/Multilayer-Ceramic-Capacitors-MLCC-SMD-SMT_Samsung-Electro-Mechanics-CL21A226MAQNNNE_C45783.html
.1uF | C6 | C_0805_2012Metric | C49678 | https://www.lcsc.com/product-detail/Multilayer-Ceramic-Capacitors-MLCC-SMD-SMT_YAGEO-CC0805KRX7R9BB104_C49678.html
330uF | C7 | SMD,6.3x5.8mm | C176319 | https://www.lcsc.com/product-detail/Solid-Capacitors_APAQ-Tech-6R3AVEA331M0606_C176319.html
220uF | C8 | CAP-SMD | C259967 | https://www.lcsc.com/product-detail/Solid-Capacitors_Nichicon-FP-6R3ME221M-SLR_C259967.html
Green_LED | D1 | LED_0805_2012Metric | C2297 | https://www.lcsc.com/product-detail/Light-Emitting-Diodes-LED_Hubei-KENTO-Elec-KT-0805G_C2297.html
SMA4734A | D2 | SMA(DO-214AC) | C2917848 | https://www.lcsc.com/product-detail/Zener-Diodes_ZHIDE-SMA4734A_C2917848.html
Red_LED | D3 | LED_0805_2012Metric | C84256 | https://www.lcsc.com/product-detail/Light-Emitting-Diodes-LED_Foshan-NationStar-Optoelectronics-NCD0805R1_C84256.html
1N4148W | D4 | SOD-123 | C81598 | https://www.lcsc.com/product-detail/Switching-Diode_ST-Semtech-1N4148W_C81598.html
MINISMDC150F/16-2 | FUSE1 | F1812 | C315955 | https://www.lcsc.com/product-detail/Resettable-Fuses_Littelfuse-MINISMDC150F-16-2_C315955.html
1.5K | R1 | R_0805_2012Metric | C4310 | https://www.lcsc.com/product-detail/Chip-Resistor-Surface-Mount_UNI-ROYAL-Uniroyal-Elec-0805W8F1501T5E_C4310.html
300R | R2 | R_0805_2012Metric | C17617 | https://www.lcsc.com/product-detail/Chip-Resistor-Surface-Mount_UNI-ROYAL-Uniroyal-Elec-0805W8F3000T5E_C17617.html
110R | R3 | R_0805_2012Metric | C246031 | https://www.lcsc.com/product-detail/Chip-Resistor-Surface-Mount_YAGEO-RC0805FR-07110RL_C246031.html
5.1K | R4,R5 | R_0402_1005Metric | C105872 | https://www.lcsc.com/product-detail/Chip-Resistor-Surface-Mount_YAGEO-RC0402FR-075K1L_C105872.html
680R | R6,R7 | R_0805_2012Metric | C17798 | https://www.lcsc.com/product-detail/Chip-Resistor-Surface-Mount_UNI-ROYAL-Uniroyal-Elec-0805W8F6800T5E_C17798.html
2SA1015 | Q1 | SOT-23 | C181170 | https://www.lcsc.com/product-detail/Bipolar-Transistors-BJT_Guangdong-Hottech-2SA1015_C181170.html
SP0502BAHTG | Q2,Q3 | SOT-23 | C207261 | https://www.lcsc.com/product-detail/Electrostatic-and-Surge-Protection-TVS-ESD_Littelfuse-SP0502BAHTG_C207261.html
X0202AG-A-AA3-R | T1 | SOT-223-3_TabPin2 | C696248 | https://www.lcsc.com/product-detail/TRIACs_UTC-Unisonic-Tech-X0202AG-A-AA3-R_C696248.html
PESDNC2XD5VB | U1 | DFN0603-D | C110696 | https://www.lcsc.com/product-detail/Electrostatic-and-Surge-Protection-TVS-ESD_Shanghai-Prisemi-Elec-PESDNC2XD5VB_C110696.html
DX07S024XJ1R1100 | J2 | USB SMD | C134113 | https://www.lcsc.com/product-detail/USB-Connectors_JAE-Electronics-DX07S024XJ1R1100_C134113.html
 |  |  | Mouser
White RCA | J3 | THT | RCJ-043 | https://www.mouser.com/ProductDetail/490-RCJ-043
Yellow RCA | J4 | THT | RCJ-044 | https://www.mouser.com/ProductDetail/490-RCJ-044
Red RCA | J5 | THT | RCJ-042 | https://www.mouser.com/ProductDetail/490-RCJ-042
DNP | SW1

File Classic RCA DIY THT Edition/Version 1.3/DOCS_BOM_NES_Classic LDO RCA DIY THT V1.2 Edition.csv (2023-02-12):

Designator | Qty | Query | Value | Description | Price | Mouser
C1 | 1 | UVZ1E222MHD | 2200uF | Capacitor_THT:CP_Radial_D12.5mm_P5.00mm | $1.00 | https://www.mouser.com/ProductDetail/Nichicon/UVZ1E222MHD?qs=IervGVB6FOU7x4X6KRxxHg%3D%3D
C2 | 1 | FG18C0G1H103JNT00 | 10nF | Ceramic Capacitors MLCC - 0.01uF - 5% - C0G (NP0) | $0.51 | https://www.mouser.com/ProductDetail/TDK/FG18C0G1H103JNT00?qs=vNwBHymccZ%252Bw21RycOG3mw%3D%3D
C3 | 1 | FG16X7R2A334KNT06 | .33uF | Ceramic Capacitors MLCC - 0.33uF - 10% - X7R | $0.56 | https://www.mouser.com/ProductDetail/TDK/FG16X7R2A334KNT06?qs=qf2ddTMq67VlCs5DKK16%252Bg%3D%3D
C4 | 1 | FG16C0G1H104JNT06 | 100nF | Ceramic Capacitors MLCC - 0.1uF - 5% - C0G (NP0) | $0.75 | https://www.mouser.com/ProductDetail/TDK/FG16C0G1H104JNT06?qs=qf2ddTMq67VWU%252BzSLgM9lA%3D%3D
C8 | 1 | A750EK227M1CAAE016 | 220uF | Capacitor_THT:CP_Radial_D6.3mm_P2.50mm | $0.58 | https://www.mouser.com/ProductDetail/KEMET/A750EK227M1CAAE016?qs=M6jHmRuQorX%252BbkmlO9snxA%3D%3D
D1 | 1 | GBL410_T0_00601 | 4A | Bridge Rectifiers 4A/1000V low vf bridge | $0.70 | https://www.mouser.com/ProductDetail/Panjit/GBL410_T0_00601?qs=vvQtp7zwQdOZWOPgfhTt1w%3D%3D
D2 | 1 | - | - | 5mm Through Hole LED - Any Color | $0.06 | https://www.amazon.com/EDGELEC-100pcs-Resistors-Included-Emitting/dp/B077XDN49X
J1 | 1 | Power Jack | PJ-037A | 2.1mm ID, DC Power Supply Connector, 2 Pin | $0.68 | https://www.mouser.com/ProductDetail/CUI-Devices/PJ-037A?qs=WyjlAZoYn53bdNRXfildEA%3D%3D
J3 | 1 | White RCA | RCJ-043 | Left Audio - White RCA Jack | $1.64 | https://www.mouser.com/ProductDetail/CUI-Devices/RCJ-043?qs=WyjlAZoYn518Y1bnzBVySQ%3D%3D
J4 | 1 | Yellow RCA | RCJ-044 | Video Out Yellow RCA Jack | $1.64 | https://www.mouser.com/ProductDetail/CUI-Devices/RCJ-044?qs=WyjlAZoYn50SPBJvOy7ojw%3D%3D
J5 | 1 | Red RCA | RCJ-042 | Right Audio - Red RCA Jack | $1.64 | https://www.mouser.com/ProductDetail/CUI-Devices/RCJ-042?qs=WyjlAZoYn51fgBDaFkMuLQ%3D%3D
Q1 | 1 | KSA1015YTA | - | Bipolar (BJT) Transistor PNP 50 V 150 mA 80MHz 400 mW | $0.44 | https://www.mouser.com/ProductDetail/onsemi-Fairchild/KSA1015YTA?qs=ljbEvF4DwOP4wK7PS53%252BtA%3D%3D
Q2 | 1 | L78S05CV |  | Linear Voltage Regulators 5.0V 2.0A Positive | $1.12 | https://www.mouser.com/ProductDetail/STMicroelectronics/L78S05CV?qs=sepekKm5O7lXLQm2U%2FAl6g%3D%3D
R1 | 1 | MFR-25SFTF52-4K7 | 4.7K | Carbon Film Resistors - Through Hole 1/4W 4.7K Ohm | $0.10 | https://www.digikey.com/en/products/detail/yageo/MFR25SFTF52-4K7/9144664
R2 | 1 | MFR-25FBF52-300R | 300 | Carbon Film Resistors - Through Hole 1/4W 300 Ohm | $0.10 | https://www.digikey.com/en/products/detail/yageo/MFR-25FBF52-300R/9138132
R3 | 1 | MFR-25FBF52-110R | 110 | Carbon Film Resistors - Through Hole 1/4W 110 Ohm | $0.10 | https://www.digikey.com/en/products/detail/yageo/MFR-25FBF52-110R/12804
- | 1 | Heatsink | - | HEATSINK ANOD ALUM TO-220 | $0.72 | https://www.digikey.com/en/products/detail/assmann-wsw-components/V4330N/3511519

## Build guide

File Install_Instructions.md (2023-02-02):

# NES-Power-Module-Installation Instructions

<ins>Items Needed</ins> 
- Soldering Iron - https://www.amazon.com/gp/product/B089SKWMPT
- Solder - https://www.amazon.com/MG-Chemicals-Leaded-Solder-Pocket/dp/B072JQ1JH4
- Soldering Wick - https://www.amazon.com/SRA-Soldering-Desoldering-Damage-Free-Removal/dp/B09PZLZSNT

<ins>Items Optional </ins> 
- Soldering Tips *(the one that come with the Iron are garbage)* - https://www.amazon.com/gp/product/B08QTW4LH5
- Flux - https://www.amazon.com/AMTECH-NC-559-V2-TF-clean-free-tacky-hand-soldering/dp/B09NXCPNN3
- Solder Sucker - https://www.amazon.com/Teenitor-Solder-Sucker-Desoldering-Removal/dp/B0739LXQ6N

<ins>Tips</ins> 
- Always leave solder on iron when putting away. This will help the tip not to oxidize.
- Use a thick tip so that lots of heat can transfer to the solder wick.  Fine tips do not transfer heat well.
- After Iron has heated up, clean the solder off on a sponge or brass cleaner and then tin the tip.
- Do not go above 350 C on your soldering iron *(only exception will be for the large ground pads)*
- Only leave the iron on the point for a few seconds, the longer you wait, the large the chance of pulling up the pad.
- Use extra flux on the Solder Wick will help it quickly pull the solder out.
- Put new solder and flux on all joints you want to desolder.  *(Larger Solder masses will suck up easier)*

<ins>Instructions</ins> 

On the Chip side of the NES Main Board, Remove the metal shield over the Power Module.


Desolder the below 5 Pins highlighted in Yellow.  Soldering Wick or a Soldering Gun should be used.
Make sure each pin can move freely before moving on to the next step.


Flip the board over and desolder the ground points highlighted in Yellow.  Do NOT desolder the 5 pins in red.


Carefully lift off the power module, This is what it will look like when the power modele has been removed.


Position the new NES Powerboard on the pins, level and then solder it on.



Connect a ground wire from the new NES Power Board to the ground plane on the main NES Board.
The console will not power on if this is missed.  Please make sure to verify you have done this correctly.



#<ins>Tips for using Solder Braid</ins>

Place the braid over unwanted solder, preferably on the greatest solder build up so that it maximizes the contact of the braid to the surface area of the solder.

Next, place your iron tip over the wick at 45 degrees and allow heat to transfer to the pad. Molten solder will absorb into the braid.

Move the solder tip and braid as needed to remove all of the solder at one time. Careful not to drag the braid over the pads, which can scratch.

Once the braid is full of solder, you must trim the spent portion and move to fresh braid in order to pull more solder. 

Remove the iron and braid simultaneously to avoid soldering the wire to the board.

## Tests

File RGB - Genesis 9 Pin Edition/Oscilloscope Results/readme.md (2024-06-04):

Testing consited of constant current of 1.5 - 2 amps. <br> <br>

My testing Setup <br>

<br> <br>
Ossiloscope used for testing: RIGOL DHO814 <br>
Parameters: <br>
- Bandwidth 20Mhz. <br>
- AC coupled. <br>
- 10x Probe. <br>
- measured with the spring on the probe across the output capacitor. <br>
- Tested multiple Boards to make sure it was consistent. <br>
- Tested at 1.65 Amps Constant Current.
  
Results
- 23.2mV pp
- 5.7mV RMS



<br> <br>
Zaxour was also willing to test this board.  Please show him some love!! https://twitter.com/zaxour <br>
Here are his results. <br> <br>

Ossiloscope used for testing: RIGOL DS1202 <br>
Parameters: <br>
- Bandwidth 20Mhz. <br>
- AC coupled <br>
- 10x probe. <br>
- No Probe spring was used so the dimmer spiky noise can be ignored. <br>
- Tested at 1.9 Amps Constant Current <br> <br>


<br> <br>
Showing the A/C Results at 1.9 Amps. <br>


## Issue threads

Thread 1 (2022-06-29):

BOM parts are back ordered,out of stock, or expensive.

acfsas, 2022-06-29:
I was in the process of ordering the parts for the Rev D Through Hole RF as Composite Video Only Edition version of this board and I quickly found the parts listed are back ordered, out of stock, or expensive. I used the BOM found here https://github.com/ShawMerlin/NES-Power-Board/blob/master/Bill_of_Materials_NESPowerPCB_TH_BOM_Mar2022.xlsx
Image for reference:
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

ShawMerlin, 2022-06-30:
Thank you for letting me know, that BOM is several months old.  Let me update it and find in stock parts and try and reduce cost.
-Merlin Shaw

ShawMerlin, 2022-06-30:
Not sure where the OctoPart is getting some of these values, I wonder if my format for the BOM doesn't match their specs.  Your picture shows the 9 Pin Gen 2 Port as water pipe costing $3000.  if you click the link, it takes it to Mouser where the part costs $3.29...  Let me do some checks on this Octopart and see if I can get a list that will play nicely with it's algorthm.

https://www.mouser.com/ProductDetail/CUI-Devices/MD-90SM?qs=WyjlAZoYn53AvrHguf2LdQ%3D%3D

acfsas, 2022-06-30:
Thank you!

ShawMerlin, 2022-06-30:
I have entered all the parts needed for the Composite Video Only Board on Octopart's BOM Generator.  You can access it at the below link.  I will work on getting the BOM excel files updated to play nicely with it.  Puts all parts needed for 1 board at $12.
Everything will be at Mouser as that is the part supplier I use but there are some parts at Digikey as well.

https://octopart.com/bom-tool/vQfUDfYZ

Let me know if there are any further concerns with this part list.
Thanks,
-Merlin Shaw

ShawMerlin, 2022-06-30:
I have used the Octopart's BOM Tool to generate a web link to the parts needed for the Fork of Spink's Rev D Composite Video Only board.  I will work later tonight on updating the excel but have deleted it at this time.  Use this link to get the parts needed, total comes to $12 for 1 board.  Everything can be obtained on Mouser as that is the part supplier I use, Digikey also holds most of the parts.

https://octopart.com/bom-tool/vQfUDfYZ

Let me know if you have any further concerns with the BOM's
Thanks,
-Merlin Shaw

acfsas, 2022-06-30:
So why is Mouser confusing one part for another? On my Mouser shopping cart I have
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
instead of
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
Octopart seems to know what specific parts are listed on the BOM while either Mouser or DigiKey doesn't? IDK?

acfsas, 2022-06-30:
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
My Mouser list

ShawMerlin, 2022-06-30:
Those Manufacture numbers do not even match what I put in Octoparts.  not sure why it's pulling the wrong parts.  I will do some more digging.

ShawMerlin, 2022-06-30:
On the OctoPart Link, when I click Mouser Buy Now, it adds all the parts correctly.  Perhaps you still had older items in your cart.  Go clear your entire Mouser Cart and then click the Buy Now again from OcotPart.

ShawMerlin, 2022-06-30:
Those extra parts are amounting to all the extra costs that is shown on that picture.  Having it cleared, it should be around $21 after shipping.

acfsas, 2022-06-30:
Alright...
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
Why is duplicating the parts?

ShawMerlin, 2022-06-30:
Did you clear the whole cart or just the first 4 items?

That looks correct for ordering enough parts for 2 boards.
Let me find a replacement for the LED light.  What color do you want for the power LED?

acfsas, 2022-06-30:
I cleared the whole cart. I don't mind the color- what is the led used for?

ShawMerlin, 2022-06-30:
I updated the BOM Tool on Octopart to include an in-stock LED.
You can delete the backordered ones and order this part.  It's a blue LED.

[150080BS75000](https://www.mouser.com/ProductDetail/Wurth-Elektronik/150080BS75000?qs=2kOmHSv6VfT2tBo3UPVqAQ%3D%3D)

acfsas, 2022-06-30:
Thanks dude

ShawMerlin, 2022-06-30:
Anytime, I will have the other BOM's up tonight.

Closed 2022-06-30.

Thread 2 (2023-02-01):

What happened to the Classic RCA DIY THT Edition?

NovenTheHero, 2023-02-01:
I went to go get the files and apparently they have been deleted.

ShawMerlin, 2023-02-01:
After it tested good, I noticed later that the inductor was getting far too hot during longer sessions so I pulled the files in order to come up with a better solution.

That was a while ago so I apologize about not having anything.  I will see if I can work on something this weekend for it.

Thanks,
-Merlin Shaw

NovenTheHero, 2023-02-01:
Oh awesome thanks man, I was just curious =)

ShawMerlin, 2023-02-14:
@NovenTheHero

Just wanted to let you know that I have uploaded the new gerbers and BOM for the DIY Board.

https://github.com/ShawMerlin/NES-Power-Module-Redesign/tree/main/Classic%20RCA%20DIY%20THT%20Edition

Let me know if you have any questions on it!!

Thanks,
-Merlin Shaw

NovenTheHero, 2023-02-15:
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

Oh awesome thanks a ton!

Closed 2023-02-01.

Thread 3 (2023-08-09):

Schematics are available only in KiCAD format, or not at all for most of the boards.

rfmerrill, 2023-08-09:
I was able to find one png screenshot of the schematic but that is it.

For someone who has the board in hand and is trying to troubleshoot an issue, repair, or anything similar to that, a readily available schematic is always handy.

You could argue everyone should have KiCAD, but honestly that opens things up for people to say the same thing as other free or shareware EDAs.

ShawMerlin, 2023-08-09:
At this time I won't be able to provide any further schematics because I just don't have the time to put into any more documentation.
I apologize if this doesn't live up to your expectations.  There is only so much I could get done with these and now I have to focus on other aspects in my life.

Closed 2023-08-09.

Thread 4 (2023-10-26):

LDO THT Board BOM is expensive because of overkill parts

flettpatrick, 2023-10-26:
I tweaked the BOM to prevent people from having to order from Digikey, Mouser, and Amazon, and merged it all into one Digikey BOM to save on shipping costs. I also added prices to show that buying 10 of each piece would reduce the fully assembled PCB cost if they managed to get 9 other people interested in buying them (most PCB fab houses require ordering 5-10 boards minimum anyways). I changed C0G caps to X7R, switched form Nichicon to Panasonic with same approximate performance ratings, and also removed 100V caps in favor of some cheaper 50V caps since the highest voltage entering this board is approx 9V AC/DC. I would argue that you could even bump the 2200uF cap down to 16V instead of 25V, but I didn't want to bother with that one that much. The spreadsheet is down below. Feel free to steal this or any part of this for your next BOM version. Thanks! :)

https://docs.google.com/spreadsheets/d/1N5DvwrXRiYk291FSXcJ2-mtGektX3NYngcAIhR5h08c/edit#gid=0

ShawMerlin, 2023-10-27:
Thank you for your work.  I am no longer developing these but I will leave this post up so that others can see it.

Closed 2023-11-13.

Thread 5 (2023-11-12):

NESRGB Companion board: No power

Scyllinice, 2023-11-12:
Hello,

I built up one of the aforementioned boards and can't seem to get the NES powered on. I did not forget the ground connection to the main board.

I followed the 9 volts around and it comes up everywhere I think it should.

Do you have any suggestions on what to look for?

I should note that the power led on the board also doesn't light up. Should it light up when the board isn't soldered to the NES?

Scyllinice, 2023-11-13:
I built up another one just to make sure I didn't do anything wrong.

It worked for a couple of power cycles and then abruptly stopped working.

This is the 2.1d Genesis version

ShawMerlin, 2023-11-13:
@Scyllinice

I hope you saw my email on the other thread but let me address some things here.

If the board is not soldered to the NES, then the power LED will not light up unless the top 2 pins on the 5 pin intererconnect are shorted across, you can use a pair of needle nose plyers to short these 2 pads in order to test the board.

These top 2 pins are labelled, 9 volt out and 9 volt in.  The out pin goes to the power switch on the front and then it comes back and feeds into the 9v in pad which powers it when the power switch is depressed.  So by sorting out those 2 pads, it simulates the power button being pressed.

At this point, you should get a power led light as long as the solder jumper is connected that is next to the LED.

Where did you have these boards made from?  I noticed from JLCPCB that some of the boards had solder paste still on them so when the chip heated up, it shorted out the input and output on the voltage regulator.  Before is sent boards out to anyone, I would do a 2 Amp load test on the board for a few hours just to make sure there we not manufacturing defects like this.

If I were to redesign the board (which I do not have time for anymore)  I would use a TE Voltage Regulator that would have a bigger footprint to allow for assembly houses to have greater tolerances on the requirements.

Let me know what you find out when shorting out those pins and if you have any other quetions, i will do my best to help you out however I can.

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

Thanks,
-Merlin Shaw

Scyllinice, 2023-11-13:
Hello,

I did see the other issue. I'm going to check to see if I can get something to happen on the board that worked for a few cycles.

I did get mine made from JLCPCB. I didn't get any of the boards assembled there. I assembled it by hand so if there are assembly problems, it would be all on me.

I'll report back if I find anything interesting.

Thanks for making the board and taking the time to answer the issue!

Scyllinice, 2023-11-25:
I finally got my NESRGB installed and everything is working great. Thanks!

Closed 2023-11-25.

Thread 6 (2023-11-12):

How to power the NESRGB board? (Genesis 2 RGB version)

jdfr228, 2023-11-12:
I built one of these myself, the Genesis 2 version, and got power on the console (power LED lighting up) but seemingly no power to the NESRGB board.

A regular NESRGB install in a frontloader has you hook up a separate voltage regulator to feed it with cleaner 5V power.  Since this board is already redesigned from the ground up I figured the whole point is the 5V coming off of it is clean.  So I read 5V on the PPU and an odd 1.6V or so on the NESRGB, and decided to jumper J3 to connect PPU 5V (end pin at the top left) to the NESRGB's 5V line.

It very briefly lit up and then everything turned off.  Now I get no power LED on the system, even with the J3 unjumpered and nothing on the NESRGB board.  I forget where my voltages were at afterwards but clearly I blew something.

So how is power supposed to be hooked up to the NESRGB board with this installation?  I didn't see any instructions about this on this github which I found odd, and especially sucks if it did cause me to blow something expensive to replace (kind of doubting the NES has handy fuses installed...)

Scyllinice, 2023-11-13:
Obviously not the author, but I have a couple of questions:

1). Was it the 2.1d version of the board?
2). How long did it work before it stopped working?

I build up a couple of 2.1d version boards and neither worked more than a few power cycles before failing. The first one didn't get as far as making the power button LED light up.

I wonder if there's something electrically unsound about that version.

jdfr228, 2023-11-13:
Yup, 2.1d. I swapped some parts out for availability reasons but followed their datasheets.

Stopped working as soon as I jumpered the pad to give the NESRGB power (J3). Will give the original power board a try once I'm back at it.

How did you power the NESRGB? J3, extra regulator, a wire to 5V, anything?

Scyllinice, 2023-11-13:
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

My NESRGB arrives this week, so my builds failed without it being involved.

I built following the BOM (I didn't notice the BOM included parts that don't exist on the board). I didn't swap any parts.

I have seen one YouTube video where one of these boards was paired with the NESRGB and it was powered via the j3 jumper. No problems there, but I don't think it was the 2.1d version of the board.

jdfr228, 2023-11-13:
Interesting - definitely curious if you can get things working with the NESRGB, even if it's briefly. Would appreciate if you'd measure the voltage on the NESRGB's 5V line before jumpering J3 as well.

I'll also look sometime this week to compare the difference between 1.9 and 2.1d. Maybe something will jump out.

Scyllinice, 2023-11-13:
I will do so.

I know the 2.1d version rearranged things, but most parts are the same. The standout to me was that the 2.1d version uses a different bridge rectifier. If I wasn't already frustrated with the outcome so far and I needed more components, I'd order the previous bridge rectifier part and see if things play out differently. I just can't justify ordering a single part.

ShawMerlin, 2023-11-13:
@Scyllinice - @jdfr228

I am sorry to hear your experiences have been poor on this board.  If you want to send me a private email, I will get some information from you both and send you boards that I have tested here myself and that are working.

We did update the bridge rectifier on the new version as it could handle more amps, the older one was getting pretty hot and we felt better about having it be over spec'd to handle all loads.

As long as the top pin on the 5 interconnect pins is showing 9-12v DC then the bridge rectifier wouldn't be the issue.
if you have 9V - 12v showing on the 2nd pin down on the 5 interconnect pins, this is the output from the switch and means it's feeding 9v's into the voltage regulator.

If you have 5 volts out on the 3rd pin down from the 5 pin interconnect but only 1.6 volts showing on the NESRGB.  I don't know what would have caused that and I personally have not seen that before.   Perhaps put a jumper from the 3rd pin down which is 5v out to the 5v in pad on the NESRGB to bypass the NES Main board.  Just a thought.

Please let me know if you have any questions and I will do my best to answer them.

Thanks,
-Merlin Shaw

Scyllinice, 2023-11-13:
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

If you've got some built up and working already, I'd certainly pay you for one and send you back the 3 remaining unpopulated boards I have from JLCPCB if you want.

ShawMerlin, 2023-11-13:
Just shoot me an email to merlin.shaw@gmail.com and I will get you taken care of.

jdfr228, 2023-11-14:
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

I'm willing to keep trying things to see what's going on, unless you have multiple extra Genesis 2 RGB boards lying around.

I'll put the original power board back in to make sure nothing's fried.  Then try the new while checking voltages and making sure everything matches what you said it should.

Can you confirm that jumper J3 on the NESRGB shouldn't be bridged?  You make it sound like the NESRGB should be getting 5V on its own, though I'm not sure where it would be pulling it from?  Since the original schematic has you connect the replacement regulator to the 5V pad on it, I don't know where it would pull 5V without J3 or a 5V wire?

ShawMerlin, 2023-11-14:
@jdfr228 - Send me an email to merlin.shaw@gmail.com and I will get you taken care of

ShawMerlin, 2023-11-14:
@jdfr228 - On my NESRGB, I have J3 soldered so it pulls the 5V from the Main NES Board.  The Main NES Board gets it power from Pin #3 of the 5 Pin Interconnect so it should all work.

If you are getting less than 5v on J3 then I would suggest not bridging that point and bring the 5v directly from Pin 3 with a jumper wire so that it's going directly to the RGBNES, this bypasses the route through the NES Main Board.

Send me an email and I will get you a few boards that I have made.

Thanks,
-Merlin Shaw

jdfr228, 2023-11-14:
Ah okay, probably want to ping @Scyllinice as well.

I had a seemingly stable 5V on the PPU pin J3 connects to before soldering J3, so I figured that was the trick to get proper 5V to the NESRGB, but maybe whatever that odd 1.6V was caused issues and overloaded that line.  Will look into it more when I'm back home at my soldering station.

ShawMerlin, 2023-11-14:
I am also in communication with @Scyllinice.

I am not sure why it would voltage would be dropped to 1.6v, especially if you have 5v on Pin #3 on the Power Board.  This one is labeled 5v Out.

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

jdfr228, 2023-11-14:
The weird 1.6V was before I soldered J3. So like the NESRGB was picking up an odd voltage from somewhere. So maybe it partially shorted the 5V line to ground, or 6.6V was fed to things and fried something.

Hopefully nothing was permanently damaged but the possibility is there and I can't imagine the NES was designed super well for over voltage protection.

Scyllinice, 2023-11-25:
I finally got my NESRGB installed. I didn't have any weird voltages before closing J3. Everything is working great for me.

Did you board survive in the end?

jdfr228, 2023-11-25:
My board appears to be fine, the NES powers on and voltages seem okay. I ended up disconnecting one wire at a time to check where that voltage was coming from, and I guess I had a short on the controller wires at the bottom right?

What's stopping me at the moment is actually having Genesis 2 cables to test with, my usual supplier is out of commission, and the composite output still doesn't work. I will be swapping the composite and audio connectors with ones in the kit ShawMerlin kindly shipped out since I bought the wrong mounting type, so hopefully they work after that, though I connected a wire manually that should have done the trick...

Suppose there's a remaining chance I damaged something but hopefully not...
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
Scyllinice, 2023-11-25:
Yeah, it's odd to me that it went dead. I swapped to a Triad 9V power supply and everything is working again. I'm not going to tempt fate on this build, but I might on the next one.

Scyllinice, 2023-11-26:
@jdfr228 Looks like I'm going to need your suggested alternative.

The BL8033 went short again, even though I did not put more than 9V in.

ShawMerlin, 2023-11-27:
The only thing in the schematic for the MP1471 that is different is it uses a 24.9K resistor while the current one uses a 10K resistor.  This is on component R4 from the diagram below.  You might be able to get the new part to work by replacing the R4 resistor with a 24.9K one.

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

ShawMerlin, 2023-11-27:
Also, the LSCS Buck Converter has a 100k resistor on R7 that is not shown on the MP1471.  You can remove that resistor and just bridge the pads together.

Let me know if this works for you as I think the MP1471 would be better to use instead of the original LSCS Part.
Thank you for all the input on this.

jdfr228, 2023-11-27:
Ah, good thing I asked for a double-check. I did indeed swap R4 out for a 24.9K one, I just forgot about that. So an extra cap and one resistor swap to change parts.

ShawMerlin, 2023-11-27:
Does everything work properly with that new voltage regulator used?

On Mon, Nov 27, 2023 at 11:30 AM James Dylan French <
***@***.***> wrote:

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

jdfr228, 2023-11-27:
Personally I hadn't used the other one, it's been MP1471 from the start on mine. I haven't needed to open your board up yet Shaw and will hopefully be able to pass the favor along to someone else who needs one.

My main holdups are cables, since I use VGA connectors for all my RGBS stuff, and a scaler, since I actually moved recently and don't have my OSSC with me, and am waiting patiently on the RetroTink 4K to launch. I may have to go grab the OSSC just in the interest of testing things, though I need to swap around composite video and csync signals to confirm my NESRGB install is working via composite at least.

Scyllinice, 2023-11-27:
If the MP1471 is working, then it stands to reason that the suggested newer MP1477 part would also work with a new board revision that switches the pinout around. It looks like pins 1 and 3 switched places as well as pins 4 and 6.

ShawMerlin, 2023-11-27:
The tagline not recommended for new designs doesn't bother me too much, as
long as there is plenty of stock, things go years and years still being
available to purchase after going EOL.

I think that disclaimer is more for people that are going to mass produce
thousands and thousands of a design.  At that point, it might not be wise
to use an EOL Part.
But for us hobbyist that are going to use a dozen.  I see no reason not to
use those in new designs.  If that makes sense.

Thanks,
-Merlin Shaw

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

jdfr228, 2023-11-28:
Grabbed the OSSC to test and my NESRGB install is fully working now with the power board with the MP1471 and two circuit tweaks (extra cap and resistor value swap).

Can't say my situation was ever as bad as yours @Scyllinice but should I test various power cycles or leaving it on overnight or something?  Seems stable here but I don't plan on playing NES much this week (don't have the OSSC remote and its current settings didn't look great...)

Scyllinice, 2023-11-28:
If you can power it back up tomorrow with no issues, then you're in good shape. That'll be better than me.

It'll be good data to have.

jdfr228, 2024-01-06:
> If you can power it back up tomorrow with no issues, then you're in good shape. That'll be better than me.
>
> It'll be good data to have.

Late reply, but I'm currently playing through Bionic Commando on it with my new Tink 4K.  Looks good and no power issues so far.  I'll let you know if anything changes, but the MP1471 seems fine with the resistor value change and extra cap.  Looks quite clean to me, and I'm not even using super high-quality cables.

ShawMerlin, 2024-02-27:
Closing this thread but if anyone has a purchased board that has failed, please reach out to my email.  If you would like a replacement, we can work on a discount that would cover my costs.

Closed 2024-02-27.

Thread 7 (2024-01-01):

Board Production query (Genesis 2 RGB version)...

gingamonkey13, 2024-01-01:
Hi - Firstly, thanks for sharing your designs here - A great solution to not hacking old consoles to pieces!

I'm in the process of bringing my old NES into the 21st century, and am attempting to get a 2.1d board produced at JLCPCB.

They've just emailed me with the following issue - As a fairly new hobbyist in this field (*it's the first time I'm attempting to get a board produced myself!), any help would be much appreciated..

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

ShawMerlin, 2024-01-01:
That is strange because I have used that file a lot at JLCPCB.  If you
could send me the gerbers you have.  I would like to confirm them with what
I am using.

Also, I am about the release a new V3.0 of the power boards that will be a
better design so it might be worth waiting a few weeks for me to be able to
test out this new design.

Biggest change will be using a TE Voltage regulator and such better full
bridge rectifier.

Thanks,
-Merlin Shaw

On Sun, Dec 31, 2023 at 6:03 PM gingamonkey13 ***@***.***>
wrote:

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

gingamonkey13, 2024-01-01:
Thanks for the reply Merlin - I've attached the zip I sent through to JLCPCB (but it's just the same, untouched version from your RGB - Genesis 9 Pin Edition / Version 2.1d folder).

Good news on the v3.0 - I think I'll put a pause on it until you're done with that one.

All the best (and a Happy New Year!),
Neil

[NES_RGB_V2-1d-Gerbers.zip](https://github.com/ShawMerlin/NES-Power-Module-Redesign/files/13804063/NES_RGB_V2-1d-Gerbers.zip)

ShawMerlin, 2024-01-17:
Just wanted to give you an update.

I am testing on these new boards but so far, they are running at 5.04v with
a full 1.5 amp load on them.  Clean and Stable power which is fantastic!!
https://github.com/ShawMerlin/NES-Power-Module-Redesign/blob/main/RGB%20-%20Genesis%209%20Pin%20Edition/readme.md

Thanks,
-Merlin Shaw

On Mon, Jan 1, 2024 at 2:13 AM gingamonkey13 ***@***.***>
wrote:

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

gingamonkey13, 2024-01-27:
Hey Merlin - Hope all is well with the new boards?
Just wondering if you're any closer to releasing the gerber files, etc for the new version?

I'd already purchased most of the additional parts for the 2.1d version (from Mouser, Digikey, Amazon, etc) until I ran into the issue above with getting the board manufactured , so after your recommendation, I decided to hold out for the v3.0 board. Hopefully I can still use a lot of the parts I purchased with your new v3.

Thanks!

ShawMerlin, 2024-01-27:
Testing the 3.0 boards has been going good but there is some issues with
the GNDing from all previous boards that I need to work out.
With this new discovery, I would not recommend any of the previous models.

It should only be a few more weeks until I can get everything vetted and
independent review on the new design.
Since you have already purchased things, let me send you some of the new
designed boards for cost, I will pay for the shipping.

Just let me know how many you need and I will put you on a list, I want to
give those that have put money into the older boards a chance to get a new
one for cost.

Thanks,
-Merlin Shaw

On Sat, Jan 27, 2024 at 9:04 AM gingamonkey13 ***@***.***>
wrote:

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

gingamonkey13, 2024-01-28:
Oh, really appreciate that Merlin - Thanks!

I'd originally ordered enough parts to make up 5 boards (*the minimum number I could get manufactured at JLCPCB). re. postage.... I insist on covering all costs, as imo it should be at our own risk that we attempt to use these boards that you have designed and kindly shared with the community. I wouldn't want you to have the burden of any expense!

Not sure how I share my details with you - Just let me know what to do when you're ready.

Thanks again!
-Neil

ShawMerlin, 2024-01-28:
My email is ***@***.***
Shoot me a message and I will put your email on the list for replacements.

Thanks,
-Merlin Shaw

On Sun, Jan 28, 2024 at 5:00 AM gingamonkey13 ***@***.***>
wrote:

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

ShawMerlin, 2024-01-28:
You can contact me on my Geek Island Facebook page as it seems to not allow email on here.
https://www.facebook.com/GeekIslandGaming/

Closed 2024-11-04.

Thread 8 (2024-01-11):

Genesis 9Pin 2.d

victor7376, 2024-01-11:
Hi,

I'm making the above mentioned board & ordered most of the parts, but I've come across an issue between two documents.

On DOCS_POS_NES_PowerBoard_RGB_V2.1d.csv it states R1 is 680 ohm resistor

But on DOCS_BOM_NES_PowerBoard_RGB_V2.1d.csv it states its a 2.2k ohm resistor

Any advice which one it is please??

Cheers

ShawMerlin, 2024-01-11:
R1 is just the resistor for the Power On LED so the value really isn't a big deal.  I believe I changed it later to 2.2K so it wasn't so bright.

However, I am about to release a new RGB Module that I feel has significant improvements so you might want to hold off until the new version is released.

victor7376, 2024-01-11:
Cheers for that, I'll keep an eye on it.  I would hold off but I've already got 10 pcb's lol.

I did struggle wih getting some of the parts though but hopefully should have at least one board working next week when some orders arrive from China & USA.

ShawMerlin, 2024-01-11:
That was one of the reasons for the new design.  This time all parts will
be available from Digikey/Mouser.

Thanks,
-Merlin Shaw

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

victor7376, 2024-01-11:
perfect !!

Might put another order in lol

ShawMerlin, 2024-01-17:
I am testing on these new boards but so far, they are running at 5.04v with
a full 1.5 amp load on them.  Clean and Stable power which is fantastic!!

https://github.com/ShawMerlin/NES-Power-Module-Redesign/blob/main/RGB%20-%20Genesis%209%20Pin%20Edition/readme.md

Thanks,
-Merlin Shaw

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

Closed 2024-11-04.

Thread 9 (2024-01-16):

R5 and R6 at wrong location? (Classic Composite v2.1e)

bitdo1, 2024-01-16:
I tried loading the gerber, BOM, and POS files for Classic Composite v2.1e into https://jlcpcb.com/ and the position of R5 and R6 are not in the correct location.

Other minor things:
- J3, J4, J5 are missing from POS (the 3 RCA connectors)
- C11 50uP 50V cap has no inventory.  There were a couple 47uP 50V caps with same 0805 package to choose from.
- C8 220uF cap only had 5 in stock and I couldn't find an alternative with same dimensions

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

I saw in previous issue you are working on a new board so I'll hold off on this for now.

ShawMerlin, 2024-01-16:
Thank you for the feedback.  I will be removing this design once the new one is available but I appreciate you finding these.

The newer design (which I am currently testing) will have easier to source parts that can be bought at places like DigiKey/Mouser but also assembly at JLCPCB.

For an alternative to C8, you can use LSCS C2757945

I didn't include the Jacks in the POS as I just did those myself instead of having it assembled.  I didn't feel it was worth the cost of those connectors and soldering compared to just doing it myself.  I can include that in later releases.

Thanks again,
-Merlin Shaw

bitdo1, 2024-01-17:
Just read the "NES Revival RGBNES Companion Power Module" page.  If I am not doing NESRGB, can the 3.0 board be used as a replacement power supply with legacy composite video/internal audio?  Maybe just needs a jumper from J1 video to J8 comp.

ShawMerlin, 2024-01-17:
The NESRGB "Companion" Power Board can do internal audio/video.  These are
selected with the slide switches that are on the board.

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

Closed 2024-01-17.

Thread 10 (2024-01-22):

schematics

Radeon91, 2024-01-22:
Hi, I have tested your NES Classic USB C Powered Module board and I love it.
I would like to port it to famicom, would you mind uploading the schematic? the resettable fuse protection seems to me a very elegant solution.

ShawMerlin, 2024-01-22:
The schematic I have for it is old and I don’t think includes the crowbar
circuit.

The kicad files are on GitHub so hopefully that can help you.  I will get
to the schematic if I can but it’s really busy right now so I can’t make
any guarantees.

Thanks,
-Merlin Shaw

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

ShawMerlin, 2024-01-30:
I have updated the schematic and uploaded to the USB C portion of this repository.
There is a JPG picture and then the Kicad editable schematic in the Kicad folder.

Thanks,
-Merlin Shaw

Closed 2024-01-30.

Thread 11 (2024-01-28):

RAD2X Support?

Nibell, 2024-01-28:
Hi, i was wondering if it supports and working with RAD2X cables for Genesis 2?
[https://www.retrogamingcables.co.uk/sega/mega-drive-2/SEGA-MEGA-DRIVE-2-GENESIS-2-32X-HD-RAD2X-HDMI-480P-CABLE](https://www.retrogamingcables.co.uk/sega/mega-drive-2/SEGA-MEGA-DRIVE-2-GENESIS-2-32X-HD-RAD2X-HDMI-480P-CABLE)
Or it only works with rgb cables?

ShawMerlin, 2024-01-28:
Yes, this board will work with the Rad2x.  However a new version is being tested right now so I would not recommend using any of the older versions.

I do have one of the new 3.0 boards on my eBay if you needed one now.

Thanks,
-Merlin Shaw

Nibell, 2024-01-30:
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
Thx, i will look in to it :smile:

Closed 2024-01-30.

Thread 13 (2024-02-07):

Wrong filename for pcb schema of USB C Classic RCA

fschuetz, 2024-02-07:
Hi

First and foremost, thanks for making this amazing project.

The file `NES-Power-Module-Redesign/USB-Powered-RCA-Classic/USB-Powered-RCA-Classic/Kicad%20Files/NES_PowerBoard_USBC_Classic_RCA_V1-5.kicad_pcb` has the wrong filename. There should be a space between USB and C (NES_PowerBoard_USB C_Classic_RCA_V1-5.kicad_pcb). Otherwise KiCAD cannot find the pcbnew file.

Best,
Florian

ShawMerlin, 2024-02-07:
Thank you for catching this.  I will get that renamed so that it won't fault on anyone else.

Closed 2024-02-07.

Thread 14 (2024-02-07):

Missing Schema for Version 2.1e for the Classic Composite Edition

fschuetz, 2024-02-07:
Hi

In the folder `NES-Power-Module-Redesign/Classic Composite Edition/Version 2.1e` the schema for KiCAD is missing. I assume this is a mistake?

Best,
Florian

ShawMerlin, 2024-02-07:
My schematics are a mess and I am working on getting them cleaned up and will upload them.

Also, with the 3.0 design being tested, I would not recommend using any previous boards.  If you have already put money/time into getting boards made, send me a DM and I will work on getting you a 3.0 board.

Thanks,
-Merlin Shaw

fschuetz, 2024-02-07:
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

Dear Merlin

Thank you for the quick reply. Do I understand correctly, that V3 its not yet released? Any ETA?

As for cleaning up the schema: Do you need help with that? I can happily work on cleaning up the schema (for the new version or the old version to have it for historic reason). Just let me know if you need help.

Best
Florian

ShawMerlin, 2024-02-07:
V3 is not released but has been testing very well.

If you are interested in getting one of the prototypes, send me a DM and we
can work out price at cost only.
merlin.shaw at g-mail

Thanks,
-Merlin Shaw

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

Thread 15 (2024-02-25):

Cannot power on if console left in Standby

Nidhoegger, 2024-02-25:
Hi, first of all, thank you for your work! I really love your mod!

One problem I am facing: I modded my consoles with this power board, since my old boards were defect. It works fine if plugged in an turned on directly. But if I leave the console turned off with the (original) Power Brick plugged in and want to play, the console does not turn on. I need to  decharge the capacitor or remove power and wait ~10 Minutes, then plug it in and it will turn on.

Is there a fix for that? Did I mess anything up? That happens for 100% of the boards (I revived about 5 consoles with it, all have the same issue).

Its the Gen9 board btw.

Thank you very much!

ShawMerlin, 2024-02-25:
Thank you for reaching out.

I have not heard of this issue before and have not seen it personally on
any of the consoles that I have used the RGB board on.  I have had had an
older board in my console for over 2 years now and it always stays plugged
in.

Have you tried a different power adapter for this issue?

What version of the power boards have you been using?

Thanks,
-Merlin Shaw

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

Nidhoegger, 2024-02-25:
Hey there, thank you for the answer. The board has the Datecode 4/26/2023. I tried with 3 different Powerbricks, happens on all.

Bestm
Nidhoegger

Nidhoegger, 2024-02-25:
Hey, I will do that in the comming week and get back to you. As for the mail, it seems like its censored by github :).

ShawMerlin, 2024-02-26:
Merlin.Shaw et google

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

Nidhoegger, 2024-02-26:
So first measurement are taken. On Pin 1, which should be 9V out, I get a reading of 16V DC. When turning the NES on, it drops to 14,14V DC on PIN 1 and I get the same reading on PIN 2, PIN 3 has a steady 4,991V DC. Ill report back with the values when the NES wont turn on. I use the offical Power Brick that is rated a 9VAC with 1.3A.

ShawMerlin, 2024-02-26:
Those measurements are good for the working example. I am very interested
in how it differs when you have it not working.

Thanks again,
-Merlin Shaw

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

ShawMerlin, 2024-02-27:
You are seeing AC on pin 1?

What is the voltage rating of the 2200uF C1 capacitor that you have these
boards?

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

Nidhoegger, 2024-02-27:
25V

ShawMerlin, 2024-02-27:
The 16-17 volts DC are not alarming as your power brick for the NES is
unregulated and has no load on it while the NES is powered off.

With having a 25V capacitor, no voltage ratings are being exceeded so
everything so far is acting normal.  Hopefully it will go into this fault
condition so we can see what those voltages are at that moment.

Thanks,
-Merlin Shaw

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

Nidhoegger, 2024-03-02:
So, the funny thing is: I could not reproduce it the whole week. until I found out what is different. I have a setup with a NESRGB and its hooked up via a RetroVision HD Genesis 2 cable to a Retrotink into a HDMI Multiplexer into a Flint 4KP capture card. When I tested it this week, I did not have Video plugged in, I just had a box sitting here with only the power plugged in and nothing went wrong. Now Ive had the Video Setup hookes as well, and it acutally reproduced after one night! The underwhelming thing: I get the same reading on the pins... So I guess its nothing wrong with the power board, it is something else. It happenes on all my boxes. I dont know if the activly powered HDMI Multiplexer may inject some voltage into the board. Ill hook up my Oscilloscope later and check all the signals and pins... Its really strange.

ShawMerlin, 2024-03-02:
Thank you for your detailed analysis and your discovery on this.

What retrotink model do you have?  I would like to reproduce this here.

Thanks,
-Merlin Shaw

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

Nidhoegger, 2024-03-02:
I have a RetroTink 5X. And the HDMI Thingy is some cheap one off of amazon with no brand, but its activley powered.

ShawMerlin, 2024-04-03:
Since is the first report out of 100's of boards in the wild.  We will save this thread for future reference.

Closed 2024-04-03.

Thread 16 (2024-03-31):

Do you have a more detailed BOM for the USB-Powered-RCA-Classic?

AlbertVDS, 2024-03-31:
Do you have a more detailed BOM for the USB-Powered-RCA-Classic?
I don't seem be able to find the correct parts, or even parts for it at all.

ShawMerlin, 2024-03-31:
I can look at that to see if the parts can be more easily identified.

Although, we are about to finish a new USB C PD Power Board that will be a
lot better than this board.
The biggest issue with USB C is it allows for 4.75v to 5.75 volts and is
still considered in spec.

The NES does not like voltages under or over 5.0 - 5.1 volts so it's very
hit and miss with all the different power bricks out there.
With the USB-C PD design, we are hitting 5.07 volts perfectly, even under a
2 amp load.

Hoping to have this ready for release in the next 4 weeks,  you can shoot
me an email if you would like more information on this.

Thanks,
-Merlin Shaw

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

AlbertVDS, 2024-04-03:
Would be great if you could, because I already have the PCBs. 😅
Though if you think it's a better choice to just get the update version, then I might just do that.

ShawMerlin, 2024-04-03:
I still have extra parts for these boards.  Please send me an email and I will provide the parts for you.

ShawMerlin, 2024-04-06:
I have added website links to the parts on the BOM list.  I checked LCSC and all parts are available.

Closed 2024-04-06.

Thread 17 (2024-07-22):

NESRGB version - composite video?

Skylark13, 2024-07-22:
Hello,

There must be something I don't understand, but a quick look at the NESRGB version it seems like it only takes composite video, not the RGB from the NESRGB board?

https://github.com/ShawMerlin/NES-Power-Module-Redesign/tree/main/RGB%20-%20Genesis%209%20Pin%20Edition

The installed image even shows the RGB pads on the NESRGB are not connected to anything
https://user-images.githubusercontent.com/70423454/226394506-f0109706-81cb-4232-8296-21bb947b9209.png

Shouldn't the Genesis2 mini-din be outputting RGB from the NESRGB, and thus shouldn't this replacement IO board take that as input?

I was looking around for installation videos, and I saw this one from Long Island Retro Gaming, where the board shown takes RGB as well as composite video in: https://www.youtube.com/watch?v=_xz6iy2H0Nw  but the links to that board seem to all be dead...

Thanks in advance.

ShawMerlin, 2024-07-22:
The Main RGB Pads on the RGBNES are not used when using this board,  You need to use the a differnt location RGBNES to get the RGB before it goes through all the image processing on the RGBNES.  If you hook up to the main RGB Pads, the picture will be a lot darker as Gen2 cables have these image processing in the cable themselves.   Please take al ook at the 7 pin hookup diagram on this picture and let me know if this makes sense.

https://github.com/ShawMerlin/NES-Power-Module-Redesign/blob/main/RGB%20-%20Genesis%209%20Pin%20Edition/NESRGB%20Hookup%20Instructions.jpg

Skylark13, 2024-07-22:
Ah, interesting, I hadn't seen these wires coming from another place on the NESRGB...

Other installation videos I've seen still use the RGB pads on the NESRGB, but remove the 75ohm SMD resistors (the three next to J9 in that photo you linked) and bridge them. I guess it's 2 ways to fix the same issue. Thanks for explaining! Yes it does make sense.

Skylark13, 2024-07-22:
Thinking about it, I might want to keep the 75Ω resistors in my case, because I'll be connecting my NES with a Genesis2 to BNC cable into my Extron Crosspoint. So there will be no resistors in the Genesis2 cable's SCART head, since I have no SCART head at all :)

Anyways that's specific to my case, I'll see how I decide to do it. Thanks in any case, now I'm just waiting for the board to be in stock on your ebay!

Closed 2024-07-22.

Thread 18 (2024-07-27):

LumaCode PCB Design

Nibell, 2024-07-27:
Hi,
I was think it would be neat if a new PCB existed to support LumaCode.
Saw the KiCad files are not uploaded, so thought i will create the next best thing.
Was thinking something like this, sorry about my poor paint skills.
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
[PPUdigitizer for LumaCode](https://www.tindie.com/products/c0pperdragon/ppudigitizer-pal-only/) does not yet support NTSC, but will in the future.
Any ideas about that?
I happy to help if you need it.

Thanks,
-Linus Nibell

ShawMerlin, 2024-07-27:
Linus,

That you for your comment and I wanted to let you know that we have been working on something just like this.  :)

The Duo Mono Audio output has always been sort of a gimmick as you can simply just get a RCA splitter to use on the Red Audio Port and get the exact same results as what we are doing on the current board.

I have been wanting to move the Yellow port back to the original position for a long time now, especially for how awkward it looks to have the RCA cable jacks so far separeated when plugging it in.

We just did not have a use for that old RF output port but when I watched the video on Luma Code, which is pretty awesome!!, I had the exact same thought that you did.  :)

It is super easy just to add a large pad that folks can solder any type of external video on, like lumacode, and have it output what they desire.

My plan was to have this implemented on the Classic RCA editions for release 3.2 and hopefully it will be ready in a week or so.

Thanks,
-Merlin Shaw

Nibell, 2024-07-27:
No problem Merlin,
Saw it this week also, i will gladly test any prototype board. Don't have the PPUdigitizer yet, waiting on it to ship.
Live in Sweden so have access to pal consoles, they are pretty cheap here so just pm me and i can send you one 😄

ShawMerlin, 2024-07-27:
If you can reach out to my email.  merlin dot shaw at google then we I can list you as a tester and get you some prototypes.  :)

Closed 2024-11-04.

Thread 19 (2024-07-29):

Gerbers for 3.1c don't appear in repo?

hexbus, 2024-07-29:
https://github.com/ShawMerlin/NES-Power-Module-Redesign/tree/main/Classic%20Composite%20Edition doesn't appear to have any Gerber's in the repo that I can locate; do you plan on making these available, or are they located in a different directory structure?

Cheers,
JD

ShawMerlin, 2024-07-29:
Thank you for pointing this out, I will get those uploaded later today.

hexbus, 2024-07-31:
Thank you so much!  I also wanted to let you know how much I appreciate you redesigning these for the community!  I have my own childhood NES and a couple of other friends who I will be using these for to clean the image up on (not to mention - the power).  You have done an amazing job on these - they are very well laid out.

I wonder if I could shoehorn one of your AV models in my Famicom too - should work if I soldered it I would think.  (I might do it just to see it work, but it won't fit permanently) :)

ShawMerlin, 2024-11-04:
The Gerber files and assembly files have been added to the link above.  Thank you again for bringing htis to my attention.

The board will work in a famicom but with the size differences, it would be quite a retrofit.  There are famicom module replacements out there.

Thanks,
-Merlin Shaw

Closed 2024-11-04.

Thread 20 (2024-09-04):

NES HDMI + USB-C PD ?

Moss720, 2024-09-04:
hi,

i am wondering, if you are considering doing a USB-C PD + HDMI power module for the NES ?

ShawMerlin, 2024-09-04:
Currently with the NESRGB mod, it only outputs the RGB format which is a
different format than HDMI.

There has been past NES HDMI projects from others but they are being
produced anymore and we’re not open sourced.

There is Development going in the NES community on something called
LumaCode.  This takes a Luma video signal and then with external equipment
can output HDMI.

Since our “companion” board has an external video out hookup, you would
only simple having the move it on the RGBNES Mod from Composite to Luma and
then utilize an external device to

It’s currently still in development as the proof of concept was created on
a PAL NES.  So if you live in a country that uses PAL, this is something
you could do now.  If not, it will only be a matter of time before they
have a NTSC version.

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

Closed 2024-11-04.

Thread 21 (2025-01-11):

Use gen2 module without NESRGB possible?

danyboy666, 2025-01-11:
I have the version 3.1c and I can't get it to show anything other than a vertical and horizontal white line? The board i want to use is an opentendo which is 100% populated with componants i'm sure are all good. CIC, CPU and PPU all pulled from a working nes. So my question is, is there a way to hook the av module without an nesrgb mod?

ShawMerlin, 2025-01-11:
If you do not have a RGBNES, you can still get audio out through the AV
with the selector in the internal video position.

This board doesn’t do any video processing so if you aren’t seeing a
picture, there may be an issue elsewhere.

What you can do to troubleshoot the board is look at the voltage on the top
of the 5 interconnect pins.  It should be 12volts or higher, then check the
2nd pin with the power switch on and it should be also 12 volts or higher.
Then check the 3rd pin and you should have 5 volts on that pin.  Let me
know if you are able to test these points.

Thanks,
-Merlin Shaw

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

danyboy666, 2025-01-11:
Alright I will let you know. I don't think it's a voltage issue I think i've narrowed down to bad ram. I have a stack of 6116 they might be the issue along with a suspected bad ppu. I have a couple sets of cpu ppu along with good ram chips. I will do some more testing tomorrow i've just finished desoldering ram sockets from a working nes pcb for testing. I'm sure it's an issue on my side thanks for your great work on this I have printed several from jlcpcb already just wanted to make sure it would work without rgb mod board. Thanks alot.

danyboy666, 2025-01-11:
In your experience is it possible for a bad ppu to corrupt/break a ram chip? I've have a couple of brand new 6116 equivalents but all.seem to output the same lines on screen.

ShawMerlin, 2025-01-11:
I have never seen a ram chip impacted by the PPU but anything is possible.

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

danyboy666, 2025-01-12:
You were right. CPU/PPU are all fine. I have two sets of them. I did have an issue with a ram chip but wasn't the ones I was using for the opentendo board. I did test the voltages and like you say I get 12v on two pins, 5v on the middle pin. Switches are set to internal vid/audio. I might have to swap tge power module for an original one just for testing. I really doubt it's one of the passive componants. 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

ShawMerlin, 2025-01-12:
Are you using an actual CIC chip or one of the open source replacements?

I have heard of some of the open source CIC solutions having issues with
the rise of the buck converter which require a few different sizes of
capacitors to fix.
Let me know if that is the case for you and I can see if I can find that
info on what to try.

Thanks,
-Merlin Shaw

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

danyboy666, 2025-01-12:
Yes it is the official cic which I confirm is working. I've also saw somewherenon reddit a user having luck with swapping C44 for something lower. Altough 220pf is the same value as on the original board. Also i've tried hooking up a chinese rgb mod board. I do get some garbbled characters and lots of static on screen using composite only. Will try to post some pics. I've used an original trimmer cap as well as the original nes oscillator. All does the same output on screen.

ShawMerlin, 2025-01-12:
The YouTube channel “More fun making it” has a video of him using the
RGBNES and one of these new power boards.  He ended up having to change
capacitor values too but i think that was more related to the RGBNES
board.  It might be helpful so I thought I would share.

If you have access to a original power module, you could swap it in to take
the power board out of the equation.

Thanks,
-Merlin Shaw

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

danyboy666, 2025-01-12:
Yes it is the official cic which I confirm is working. I've also saw somewherenon reddit a user having luck with swapping C44 for something lower. Altough 220pf is the same value as on the original board. Also i've tried hooking up a chinese rgb mod board. I do get some garbbled characters and lots of static on screen using composite only. Will try to post some pics. I've used an original trimmer cap as well as the original nes oscillator. All does the same output on screen.

danyboy666, 2025-01-12:
Yes I think that would be the logical step to try to rule out anything related to the power module at least. So close yet so far lol. I'll try this tomorrow I do have acces to a power module. I even have a second opentendo board pretty much ready to test. Thanks alot for this.

danyboy666, 2025-01-13:
It only took three days of screwing around.... I should have tested with and original power module at first. 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

It's working even without the trimmer cap. Something is up with the power module I was sold I'm not sure what. I think i'll retest it just to be sure but it's almost certain it's that. Maybe a bad solder somewhere or even a bad (only)  transistor. I did check it to be sure with a diode tester but in circuit so i'm not entirely sure it's right or not but i'm not reading the same values. I'm kinda glad it wasn't my opentendo build lol.

danyboy666, 2025-01-13:
If I test with the new power module, problem is back.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

ShawMerlin, 2025-01-13:
The issue comes from a buck converter has a gradual rise to 5 volts while
the original Power Module is a LDO so it's instant at 5 volts.
This would be the same case for any switching buck converter providing the
voltage to the main board.

We have not ever seen this on the original main NES Board so there is
something with how the timing circuit is working from the new main board.
I have heard of others with OpenTendo's that had this issue with the new
power module and they had to find the right capacitor in order to get it to
work.

Too low of a capacitor or none at all means that the timing hits too fast,
too large of a capacitor means the timing hits too slow.
From my notes, it looks like the last person that had issues used a 10uF
capacitor to get his Opentendo to work with the new power module.

If the original power module is working for you, there isn't a huge impact
with using it compared to the new switching power module.

Thanks,
-Merlin Shaw

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

danyboy666, 2025-01-13:
I do have some plans with those boards so idealy would be nice to have them work on opentendos since I have some main board pcbs already printed. Do you remember which capacitor? If it's the timing circuit my guess would be C44 like i've mentioned before? It would be certainly helpful to others if they have this issue too. At least it would be documented somewhere.

ShawMerlin, 2025-01-13:
I believe it was the  10uF capacitor that he used.

There is an active discussion on it right now with the Dubesihower's
Modding group under NES-Help
https://discord.gg/MUc7uMyH

Zaxour is on that thread and has a lot of information on the timing circuit
and these capacitors.
I am sorry that I am not as much help as with analog things, timings are
very critical for the reset circuit.

I plan on documenting it on Github when there is more of a concrete answer.
Lots of Opentendo's have worked without having to mess with the timing
capacitor, only just a couple of shown this issue.

Thanks for your patience on this,
-Merlin Shaw

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

ShawMerlin, 2025-01-15:
Thank you for catching it,  For Digikey it should be 2SA1015 or KSA1015YTA.  Both will work.  I will get that updated right now.

danyboy666, 2025-01-15:
Ohhhh so I do have the wrong one installed? It says LG 416 on the package and tested as a NPN. If you're positive it an ASA2015 i'll swap it out right away :)

ShawMerlin, 2025-01-15:
Did you get this board from me on my eBay?  the JLCPCB number C181170 is correct so if these are ordered from JLCPCB, then it would have come with a 2SA1015 - https://jlcpcb.com/partdetail/GuangdongHottech-2SA1015/C181170

danyboy666, 2025-01-15:
> Did you get this board from me on my eBay?  the JLCPCB number C181170 is correct so if these are ordered from JLCPCB, then it would have come with a 2SA1015 - https://jlcpcb.com/partdetail/GuangdongHottech-2SA1015/C181170

It was a seller named kurt. It came all pre soldered.

Good thing now i'll be able to order the right parts for the boards I have here. Also there are two BOMs for the genesis 2 version and C12 is either listed as 1nF or 560pF. It's not a big difference but still. Might be a good time to validate that too.

ShawMerlin, 2025-01-15:
I will check on C12.  I do apologize for this mistake of the Digikey part number for Q1.  As more people start offering these, having accurate information will be critical for our community to get working safe devices for their legacy hardware.

I have a lab bench with a frankenstine'd NES and pogo pins that I use to test all the boards I have sold.  I have them come pre-assembled from JLCPCB with the SMD parts so I would not have caught the DigiKey part number mistake.

Thank you again for discovering that and bringing it to our attention.
-Merlin Shaw

ShawMerlin, 2025-01-15:
For C12;

Both 1nF and 560pF will work without issue.  It will work with this removed too.  The TinyNES's design added the 560pF so we changed ours to this and it does help make a more crisp picture.

So I would recommend 560pf in this location.  I will make sure the BOM's reflect this.

danyboy666, 2025-01-15:
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

Oh very nice i'll grab that new version. Thanks alot for this project. It's a board which will be very uselful to me. Not much else is needed to build an entire nes.

ShawMerlin, 2025-01-15:
Here is what i'm updating the BOM with - https://www.digikey.com/en/products/detail/kemet/C0805C561J5GACAUTO/10642381

danyboy666, 2025-01-17:
So i'm guessing by the non-answer the problem is on my side and I should deal with this on my own? Man i've spent almost a 100$ on this module that should have worked. I'll leave the rgb alone for now but still that tone is really annoying.

ShawMerlin, 2025-01-17:
I do apologize as I did not see your follow up question.

The buzzing on the sound was something that was discovered before 3.1c ever
was released or put into production.

It’s due to the buck converter itself and it’s a variant that causes this
buzzing due to its claims to reduce EMF.

If you can get a nice close up picture of the buck converter,  you should
see if their is an H or not in the part number.

If you can reach out to me on my person email.  Check out my GitHub file on
the GND loop for my address.

I will get you taken care of, i didn’t sell you the board but it was built
using my project and possible an older BOM (I will verify that too)

Thanks,
-Merlin Shaw

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

danyboy666, 2025-01-17:
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

I know it's not your problem also I really didn't want to come accross as an a**. I'll post some pics thanks again for your help. I really do apreciate it.

danyboy666, 2025-01-31:
Everything is solved. Thanks for everything sorry to see you retire this project.

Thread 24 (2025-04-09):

RGB Gerbers mounting holes on seperate drill layer

circuitsable, 2025-04-09:
Hi, I really love this project! My assembly of the RGB board was smooth and worked first try with the NESRGB. However, when going to install it into my NES I noticed the mounting holes were not drilled through. I went to check the gerber file and found these 3 holes were on the NPTH layer instead of the PTH layer, which caused my PCB board house to miss these holes. Perhaps this will be remedied by the eventual kicad source files release (allowing us to choose our own gerber export options), but in the meantime I wanted to share this potential issue. I fixed it by manually drilling holes.

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

circuitsable, 2025-04-09:
I realize this is kind of a non-issue and is the fault of my boardhouse, and will be fixed once the kicad source is released. Closing

Closed 2025-04-09.

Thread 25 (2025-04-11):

New version for PPUDigitizer

jstoneburner, 2025-04-11:
As the PPUDigitizer is becoming more popular, could a board be modified (preferably the one with dual channel audio) so that the composite video input from the NES could be disabled, and instead, connected via a wire to the PPUDigitizer? It an be done with the current boards, but just requires modification of the board, so it's a pretty minor mod.

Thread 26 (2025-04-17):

BOM for Classic Composite Edition not correct

sureal808, 2025-04-17:
R2 references 120k ohm resistor but links to a 105k resistor. Which is the correct one?

sureal808, 2025-04-17:
R1 does not have a link. Should link here: https://www.digikey.ca/en/products/detail/vishay-dale/CRCW08054K70FKEAC/7928553

nebhead, 2025-04-21:
Also, the switch listed in the BOM (SW1 | Switch | E-Switch |   | DPDT | EG2215) doesn't seem to have the correct footprint, or it's the wrong switch.  At least for the Classic THT DIY edition.

nebhead, 2025-04-21:
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

Thanks for the super fast response!

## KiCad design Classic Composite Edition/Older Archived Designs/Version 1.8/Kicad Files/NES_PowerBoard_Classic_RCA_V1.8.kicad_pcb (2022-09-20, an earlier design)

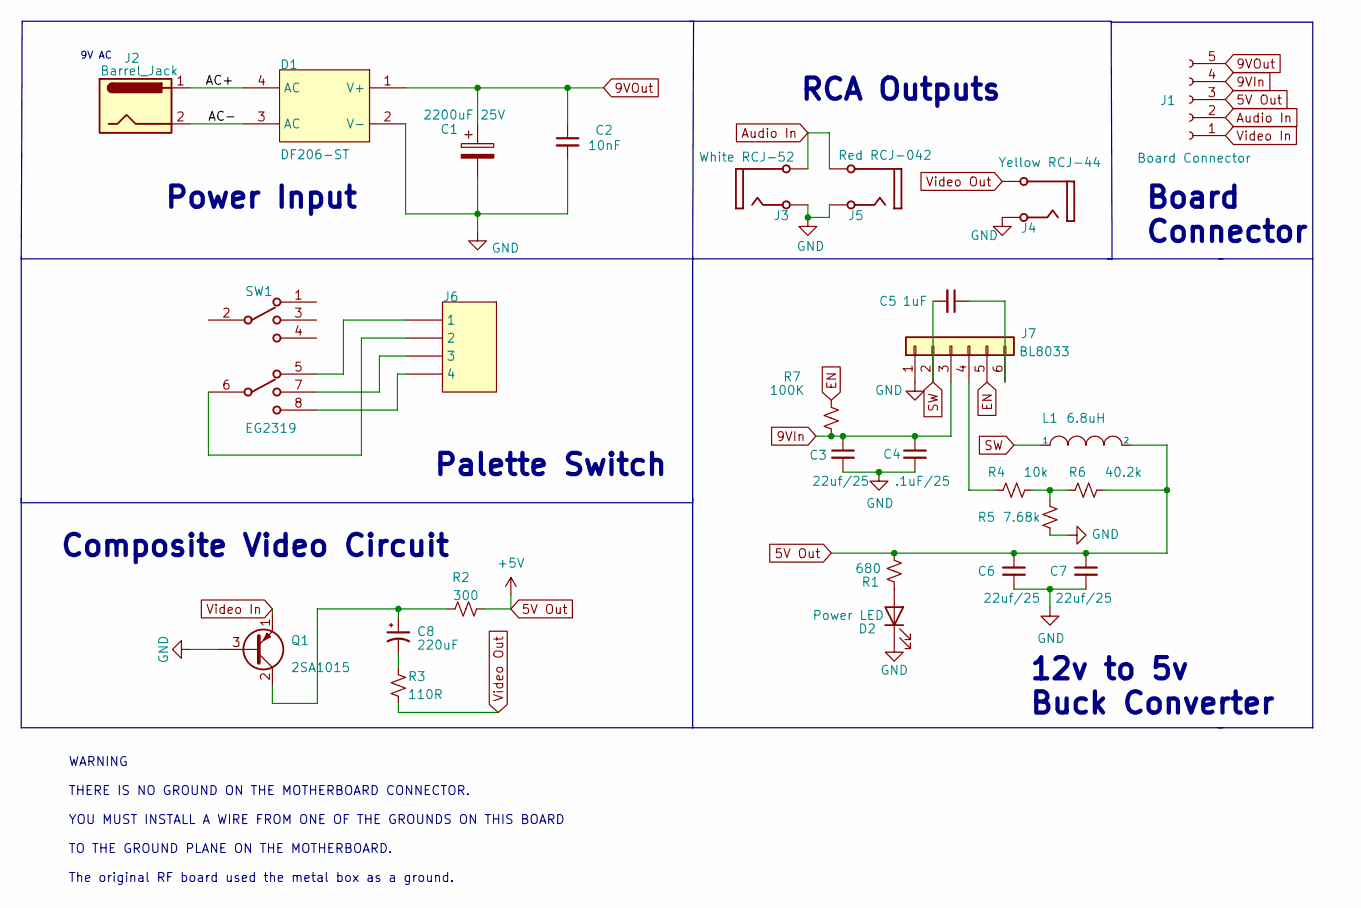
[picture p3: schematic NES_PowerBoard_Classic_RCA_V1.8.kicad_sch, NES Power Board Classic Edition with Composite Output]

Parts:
C1: 2200uF 25V
C2: 10nF; C_0805_2012Metric
C3, C6, C7: 22uf/25; C_0805_2012Metric_Pad1.18x1.45mm_HandSolder
C4: .1uF/25; C_0805_2012Metric_Pad1.18x1.45mm_HandSolder
C5: 1uF; C_0805_2012Metric_Pad1.18x1.45mm_HandSolder
C8: 220uF; CP_Radial_D6.3mm_P2.50mm
D1: DF206-ST; DFS4
D2: Power LED; LED_0805_2012Metric
J1: Board Connector
J2: Barrel_Jack; PWR-JCK-ALT (PJ-037A/B)
J3: White RCJ-52; CUI_RCJ-044
J4: Yellow RCJ-44; CUI_RCJ-044
J5: Red RCJ-042; CUI_RCJ-044
J6: Header 1x4 1.27mm; HDR1X4-15MM VERT - L
J7: BL8033; SOT-23-6_Handsoldering
L1: 6.8uH; Inductor-L_6.3x6.3_H3
Q1: 2SA1015; TO-92_Inline
R1: 680; R_0805_2012Metric
R2: 300; R_Axial_DIN0309_L9.0mm_D3.2mm_P2.54mm_Vertical
R3: 110R; R_0805_2012Metric
R4: 10k; R_0805_2012Metric
R5: 7.68k; R_0805_2012Metric
R6: 40.2k; R_0805_2012Metric
R7: 100K; R_0805_2012Metric
SW1: DP3T; SW-DP3T (EG2319)

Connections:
5V Out: C6.1, C7.1, J1.3, L1.2, R1.2, R2.1, R6.2
9VIn: C3.1, C4.1, J1.4, J7.3, R7.2
9VOut: C1.1, C2.1, D1.1 (V+), J1.5
/AC+: D1.4 (AC), J2.1
/AC-: D1.3 (AC), J2.2
Audio In: J1.2, J3.2 (Sleeve), J5.2 (Sleeve)
EN: J7.5, R7.1
GND: C1.2, C2.2, C3.2, C4.2, C6.2, C7.2, D1.2 (V-), D2.1 (K), J3.1 (Tip), J4.1 (Tip), J5.1 (Tip), J7.1, Q1.3 (B), R5.2; also elsewhere on the board
unnamed: C5.1, J7.6
unnamed: C8.1, Q1.2 (C), R2.2
unnamed: C8.2, R3.2
unnamed: D2.2 (A), R1.1
unnamed: J6.1, SW1.5
unnamed: J6.2, SW1.6
unnamed: J6.3, SW1.7
unnamed: J6.4, SW1.8
unnamed: J7.4, R4.1
unnamed: R4.2, R5.1, R6.1
SW: C5.2, J7.2, L1.1
Video In: J1.1, Q1.1 (E)
Video Out: J4.2 (Sleeve), R3.1

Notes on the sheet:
RCA Outputs
Power Input
Composite Video Circuit
Palette Switch
12v to 5v Buck Converter
Board Connector
WARNING THERE IS NO GROUND ON THE MOTHERBOARD CONNECTOR. YOU MUST INSTALL A WIRE FROM ONE OF THE GROUNDS ON THIS BOARD TO THE GROUND PLANE ON THE MOTHERBOARD. The original RF board used the metal box as a ground.
9V AC

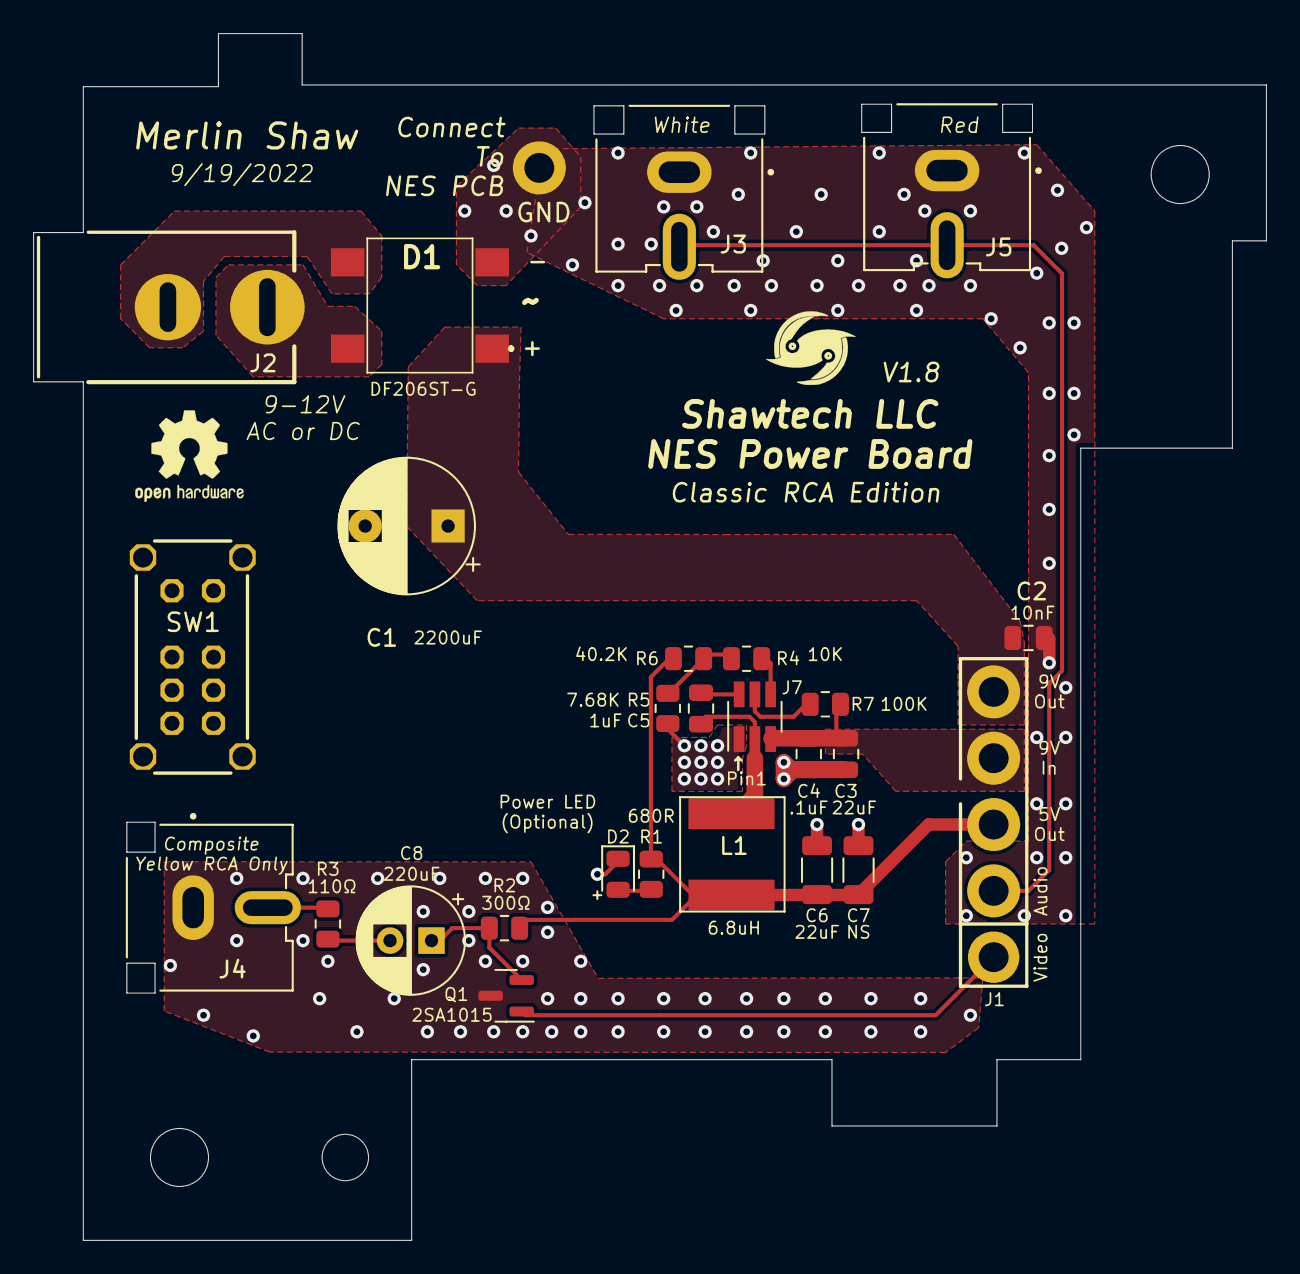
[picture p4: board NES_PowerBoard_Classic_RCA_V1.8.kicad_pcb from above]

Board: 2 copper layers, 74.3 x 72.8 mm, 27 parts (0 on the bottom side), 17 nets.

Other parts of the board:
GND: Wire Pad; WIREPAD-09-15

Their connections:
GND: GND.1; also elsewhere on the board

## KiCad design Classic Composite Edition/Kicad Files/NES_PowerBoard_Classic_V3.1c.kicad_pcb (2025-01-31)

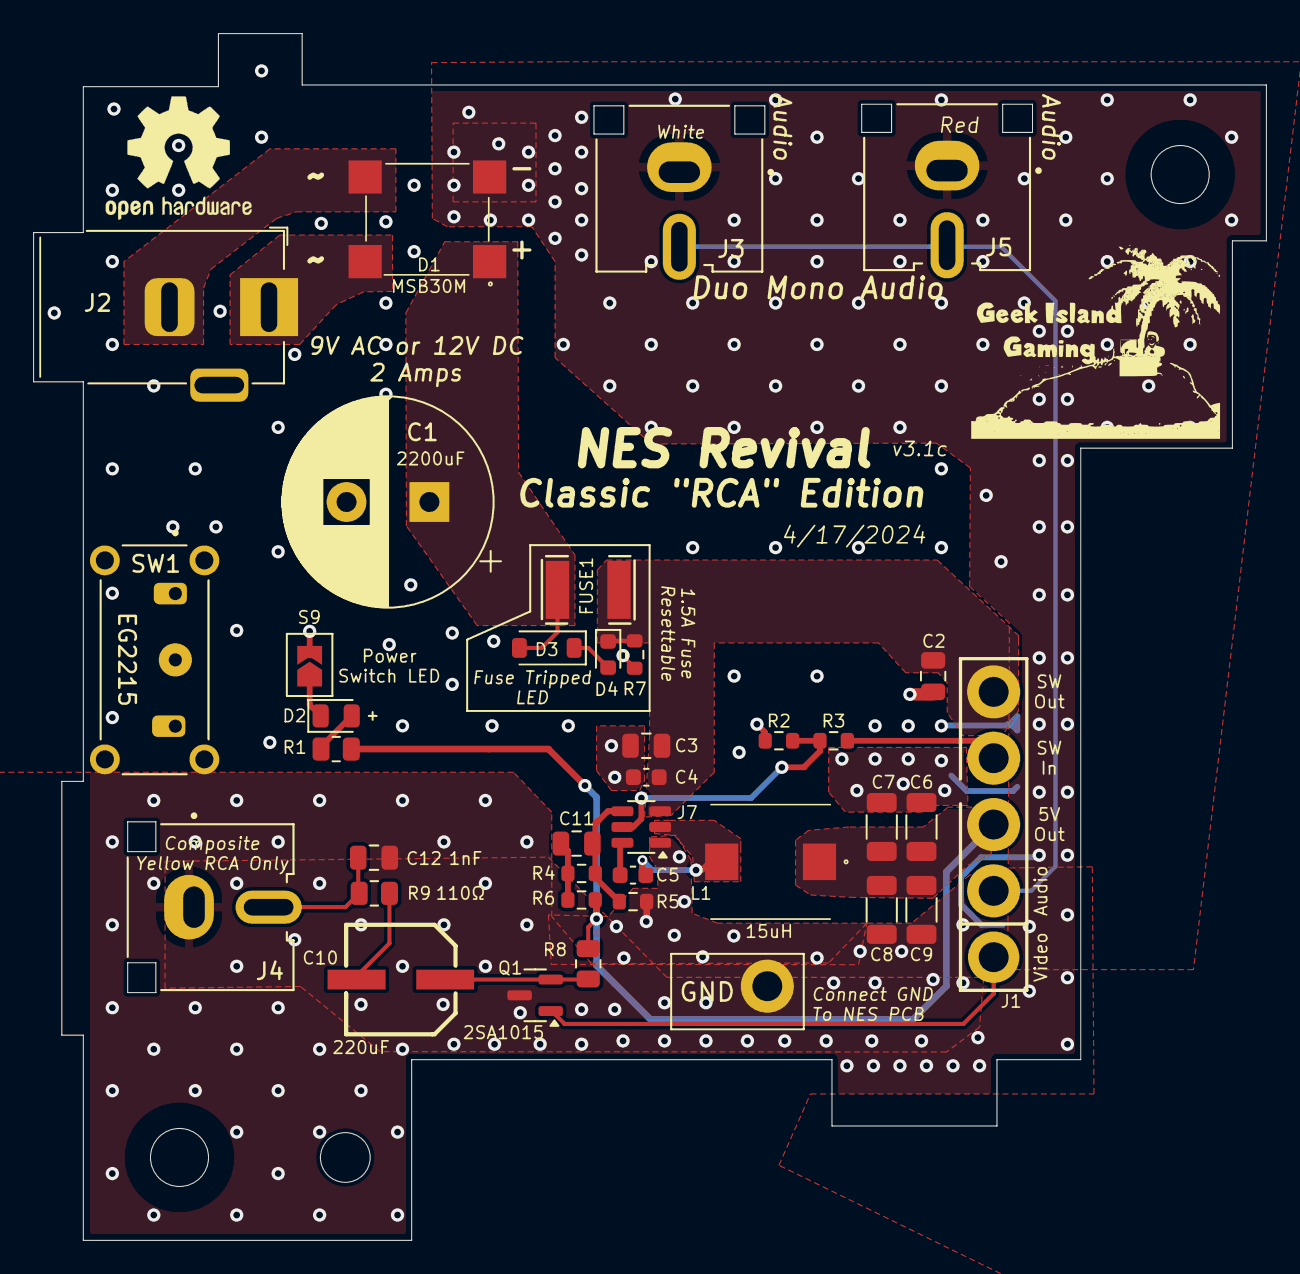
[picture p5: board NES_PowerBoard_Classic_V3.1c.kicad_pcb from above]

Board: 4 copper layers, 74.3 x 72.8 mm, 37 parts (0 on the bottom side), 20 nets.

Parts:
C1: 2200uF 25V; CP_Radial_D12.5mm_P5.00mm
C2: 10nF; C_0805_2012Metric
C3: 10uF; C_0805_2012Metric
C4, C5: .1uF; C_0603_1608Metric
C6: 10nF; C_1206_3216Metric
C7, C8: 22uF; C_1206_3216Metric
C9: .1uF; C_1206_3216Metric
C10: 220uF; NESCAP
C11, C12: 75pF; C_0805_2012Metric
D1: MSB30M
D2: Power LED; LED_0805_2012Metric
D3: 1N4148W; D_SOD-123
D4: Power LED; LED_0603_1608Metric
FUSE1: F1812
GND: Wire Pad; GND
J1: Board Connector; RF BOARD CONNECTOR
J2: EJ503A; NES_EJ503A
J3, J4: White RCJ-; CUI_RCA
J5: Red RCJ-042; CUI_RCA
J7: TPS54202; SOT-23-6
JP1: Jump; SolderJumper-2_P1.3mm_Open_TrianglePad1.0x1.5mm
L1: 15uF; CLF7045T
Q1: 2SA1015; SOT-23
R1: 4,7K; R_0805_2012Metric
R2: 105K; R_0603_1608Metric
R3: 511K; R_0603_1608Metric
R4: 100K; R_0603_1608Metric
R5: 13.3K; R_0603_1608Metric
R6: 49.9; R_0603_1608Metric
R7: 4.7K; R_0603_1608Metric
R8: 300; R_0805_2012Metric
R9: 110R; R_0805_2012Metric
SW1: EG2215; SW_EG1224

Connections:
5V Out: C6.1, C7.1, C8.1, C9.1, J1.3, L1.1, R1.2, R6.2, R8.1
9VIn: J1.4, R3.2
9VOut: C1.1, D1.1, D3.2, FUSE1.1
9VOut2: C2.1, C3.1, C4.1, D4.1 (K), FUSE1.2, J1.5, J7.3, R7.1
A: J1.2, J3.2 (Sleeve), J5.2 (Sleeve)
AC: D1.2, J2.1
AC2: D1.4, J2.2
BOOT: C5.1, J7.6
EN: J7.5, R2.1, R3.1
FB: C11.1, J7.4, R4.1, R5.1
GND: C1.2, C2.2, C3.2, C4.2, C6.2, C7.2, C8.2, C9.2, C12.1, D1.3, GND.1, J3.1 (Tip), J4.1 (Tip), J5.1 (Tip), J7.1, JP1.2, Q1.3 (B), R2.2, R5.2, R7.2, SW1.S1, SW1.S2, SW1.S3, SW1.S4
GNDD: D2.1 (K), JP1.1
ICC4: C10.2, R9.2
MX: C11.2, R4.2, R6.1
unnamed: D2.2 (A), R1.1
RCA_Video: C12.2, J4.2 (Sleeve), R9.1
SW: C5.2, J7.2, L1.2
V5: D3.1, D4.2 (A)
Vid_In: C10.1, Q1.2 (C), R8.2
Video In: J1.1, Q1.1 (E)

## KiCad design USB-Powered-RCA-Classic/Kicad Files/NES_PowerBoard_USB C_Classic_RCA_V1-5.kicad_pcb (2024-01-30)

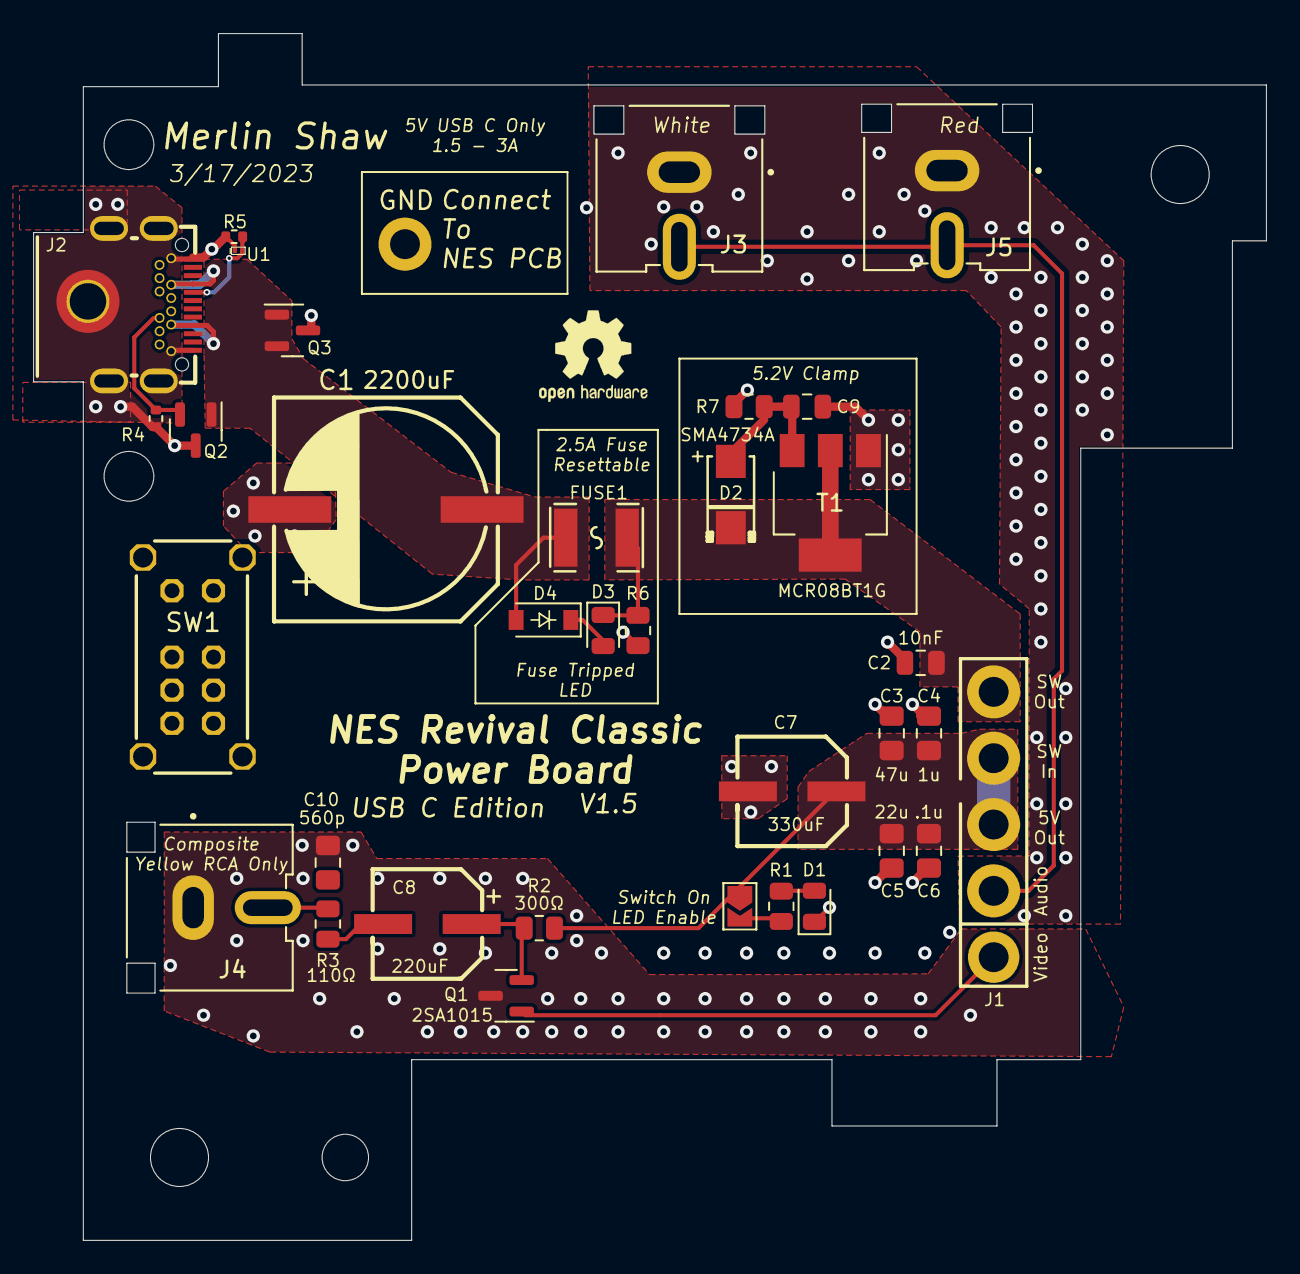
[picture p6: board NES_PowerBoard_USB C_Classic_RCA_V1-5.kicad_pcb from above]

Board: 2 copper layers, 74.4 x 72.8 mm, 35 parts (0 on the bottom side), 15 nets.

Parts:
C1: CAP-SMD_BD12.5-L13.0-W13.0-RD
C2, C9: 10nF; C_0805_2012Metric
C3, C4, C5, C6: 22uf/25; C_0805_2012Metric_Pad1.18x1.45mm_HandSolder
C7, C8: 220uF; CAP-SMD_BD6.3-L6.5-W6.5-LS7.0-FD
C10: 560p; C_0805_2012Metric_Pad1.18x1.45mm_HandSolder
D1, D3: Power LED; LED_0805_2012Metric
D2: SMA_L4.2-W2.7-LS5.0-RD
D4: 1N4148W; D_SOD-123
FUSE1: F1812
GND: Wire Pad; WIREPAD-09-15
J1: Board Connector; RF BOARD CONNECTOR
J2: DX07S024XJ1R1100; USB-C-TH_DX07S024XJ1R1100-1
J3: White RCJ-52; CUI_RCJ-044
J4: Yellow RCJ-44; CUI_RCJ-044
J5: Red RCJ-042; CUI_RCJ-044
JP1: Jump; SolderJumper-2_P1.3mm_Open_TrianglePad1.0x1.5mm
Q1: 2SA1015; SOT-23
Q2, Q3: SP0502BAHTG; SOT-23
R1, R7: 680; R_0805_2012Metric
R2: 300; R_0805_2012Metric
R3: 110R; R_0805_2012Metric
R4, R5: 5.1k; R_0402_1005Metric
R6: 4.7K; R_0805_2012Metric
SW1: DP3T; SW-DP3T (EG2319)
T1: SOT-223-3_TabPin2
U1: DFN0603-D_L0.6-W0.3-P0.34-RD

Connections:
5V Out: C3.1, C4.1, C5.1, C6.1, C7.1, J1.3, J1.4, JP1.1, R2.1
9VOut: C1.1, D4.2, FUSE1.1, J2.A4, J2.A9, J2.B4, J2.B9, Q2.1 (E), Q3.1 (E), Q3.2 (C)
Audio In: J1.2, J3.2 (Sleeve), J5.2 (Sleeve)
CC1: J2.A5, R5.1, U1.2
CC2: J2.B5, Q2.2 (C), R4.1
GND: C1.2, C2.2, C3.2, C4.2, C5.2, C6.2, C7.2, C9.2, C10.2, D1.1 (K), GND.1, J2.0, J2.A1, J2.A12, J2.B1, J2.B12, J3.1 (Tip), J4.1 (Tip), J5.1 (Tip), Q1.3 (B), Q2.3 (B), Q3.3 (B), R4.2, R5.2, R6.2, R7.2, T1.1, U1.1
GTG: C9.1, D2.2, R7.1, T1.3
LED_IN: JP1.2, R1.2
unnamed: C8.1, Q1.2 (C), R2.2
unnamed: C8.2, R3.2
unnamed: D1.2 (A), R1.1
USB_Power_Out: C2.1, D2.1, D3.1 (K), FUSE1.2, J1.5, R6.1, T1.2
V5: D3.2 (A), D4.1
Video In: J1.1, Q1.1 (E)
Video Out: C10.1, J4.2 (Sleeve), R3.1

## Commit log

2023-01-09 Create Classic USB C Powered
2023-02-12 Update DOCS_BOM_NES_Classic LDO RCA DIY THT V1.2 Edition.csv
    [DOCS_BOM_NES_Classic LDO RCA DIY THT V1.2 Edition.csv]
2024-03-01 Update GND Loop Solution.md
2024-03-06 Create Board Configurations.md
2024-03-06 Update Board Configurations.md
2025-01-31 Switch for Classic version is an EG2215
    [DOCS_BOM_NES_PowerBoard_Classic_V3.1.csv]
